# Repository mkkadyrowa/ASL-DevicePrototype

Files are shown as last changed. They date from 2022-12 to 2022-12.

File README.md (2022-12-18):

# ASL-DevicePrototype
Includes designs, circuit diagrams, signal processing code, final report, laboratory notebook

We developed design skills to produce wearable american sign language device where the main concept was to have ring and fingernail devices emit and record IR waveform emissions with specific calculated frequency. We applied electrical engineering knowledge to create IR LED data acquistion module, band pass filter, and IR wave generatitng module using chips, circuitry electronics, measurement and power tools (e.g. oscilloscope, multimeter, power supply). We presented obtained data from oscilloscope where it showed how data was produced with specific frequency, data was collected using data acquisition module, and data was filtered using bandpass filtering. We had specific functitonal specifications such as voltage limit, IR LED wavelength, and frequency generated by the IR LED emitting circuit. We researched and practiced safety and sustainability standards. We remained under the project budget, utilized Gannt and PERT charts for project management. I worked with NI Multisim to create and test circuit diagrams of IR wave generating circuit, data acquisition module, and filtering module online before creating them in the lab. We created PCB circuit diagrams for the above mentioned IR wave generating circuit, IR data detection and acquisition module. We simulated, tested, troubleshot, and tried alternative approaches for the three modules were creating using Falstad, NI Multisim, and TI online simulation tool. We soldered the circuit diagrams as SMD models and perforated board model after testing them on breadboards. The testing of the systems included having IR wave generating circuit emit IR waves in specific frequency using 5 V power input. Next, IR data acquisition module recorded IR waves with specific frequency and graphed data on oscilloscope where captured frequency and voltage was observed. Active bandpass filtering module received acquired IR data, filtered outt optical noise, and returned a filtered signal where frequency and voltage was analyzeed. I learned team and project management, testing and troubleshooting electrical prototypes, regulations and standards, presenting data and biweekly updates, finding alternative solutions, designing parts on SolidWorks, soldering, PCB soldering using SMD models, using NI Multisim for designing and testing circuit diagrams, etc.

Summary: Designed and built a wearable American Sign Language device prototype that leveraged infrared (IR) waveforms from ring and fingernail sensors with specific frequency. Used NI Multisim, SolidWorks, SMD Models.

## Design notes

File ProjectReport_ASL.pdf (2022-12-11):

Senior Design Project II (BE-4355-001)

A Lightweight Wearable American Sign Language Translation Device

Faculty Mentor: Dr.Oguz Yetkin

Team Members: Ruqaya Abdulzahraa, Savannah Chiweshe, Mahri Kadyrova, Ridhaa Shariff

Team: Vixen

Bioengineering Department at The University of Texas at Arlington

Submission Date: 26

th April 2022

2. Executive summary

The main goal of this project is to create a lightweight, wearable American Sign Language (ASL)

translation device. Currently, over 5% of the world’s population lives with a hearing disability. It is

estimated that by the year 2050, 1 in every 10 people will have a hearing disability (1). The overall aim

of this project is to create a fully functional translation device that will diminish the current

communication barrier that exists. Through our research, we found that there are many devices that are

currently being developed with similar goals. Many of these devices are glove-based, making them

cumbersome to use, as they limit the user’s ability to perform everyday life tasks. We attempt to

overcome this issue by designing the device to be glove-less with no necessity for it to be connected to

any external computers, monitors, or network. It is composed of five wireless fingernails, five wired

rings that are connected via thin wires to a wrist-worn central processing unit. The wrist-worn unit is

composed of an Arduino Mega, Raspberry Pi, and a 9V battery. These components are encased in a box-

like enclosure with a Liquid Crystal Display (LCD) screen and a speaker mounted on the side. The

device will achieve hand gesture recognition using 850 nm infrared (IR) light-emitting diode (LED)

emitters in the fingernails and rings. The IR LEDs (Light Emitting Diode) in the rings will trigger the IR

LEDs in the fingernails and thus turn them on. Each ring will have IR receivers that will be able to

measure the intensity of the signals produced by the IR emitters in the fingernails. They will then send

this information to the wrist-bound Raspberry Pi to translate it through a trained neural network, which

is coded using Python, and produce the corresponding letter to be displayed on the LCD screen and

through the speaker. Our produced device will be the 9th generation production. Previous generations of

the device relied on digital filtering, which has been proven to hinder the performance of the device as it

results in inaccurate translating different gestures. Our novelty is implementing a new analogue filtering

system, which aims to fix this issue. We envision having square waveform generators in the fingernail

devices and filters in the ring devices. The specifications that we set for this project are that the device

should be lightweight (less than 400 g) and not rely on an external computer. The functional

specifications are that the device can recognize and translate the ASL alphabet, be at least 95% accurate,

be able to differentiate different frequencies, not pose any optical hazard, and have a life span of 4

hours. One of the main specifications is that the device must be below 400 grams, after calculating the

final device weight, we measured it to be 375.88 grams, which meets the weight limit. Another criterion

is that it must not rely on any external device, which our device meets that standard. The device must,

however, be connected to a power source, such as a power bank.

3. Table of contents

5.3 Engineering, safety, environmental, and sustainability standards that are applicable and are to be observed

6.2.1 Drawings, schematics and other illustrative means of showing the system and the subsystems for the

6.5 Assessment of chances of success based on the selected design concept and engineering computations and

8.1 Detailed description of the testing procedures/protocols for determining the physical and functional

4. Introduction

4.1 Significance and benefits of the project

American Sign Language is the third most used language in the United States. Across the country, 10

million are hard of hearing and close to 1 million are functionally deaf (2). Furthermore, 2-3 of every

1000 children are born with a detectable level of hearing loss, and 90% of this population is born to

hearing parents, thus creating a communication divide within families (3). In a work environment,

accommodations for ASL users are minimal to none. Moreover, the deaf awareness training in

workplaces has low results. And in the past few years, due to Pandemic it has become more difficult for

ASL users to sign and understand their coworkers as interpreters are not always “pinned” during video

calls (4)(5).

4.2 Existing similar systems

Currently, there are no ASL translation devices on the market, but there are several institutions and

groups that have researched and designed similar devices. These institutions include Cornell University

where Electrical and Computer Engineering students designed a wearable glove that uses Machine

Learning algorithms to translate signed language into spoken English (6). This prototype uses Spectra

Symbol Flex-Sensors to measure how much a finger is bent and a three- axis accelerator and gyroscope

to identify the orientation and movement of the hand. The data from the sensors is then analyzed using

ATmega1284p microcontrollers and sent to a main PC (Personal Computer) unit and run-in conjunction

with a python script and then translated. As a result, their final device had an accuracy of 98%,

translating 28 ASL signs, however, these values are dependent on the user's hand size which creates

challenges differentiating between certain letters.

Similarly, Michigan State University developed a deep learning-based sign language translation

technology implementing Leap Motion for light-based sensing of skeletal joints. In addition to this, the

technology uses a recurrent neural network model the spatial structure and temporal dynamics of the

extracted ASL characteristics, and a probabilistic framework based on Connectionist Temporal

Classification, allowing for both word and sentence level ASL translation of 94.5% accuracy (7).

However, this design is different from other translation devices as it does not incorporate any type of

glove which other devices lean towards.

4.3 Objectives of the project

The main objective of this device is to narrow the communication gap between ASL and non ASL users

by allowing the language to be used and understood between the two parties without the need of an

interpreter. This communication barrier makes it hard for ASL users to express themselves and

communicate and the reliance on an interpreter would hinder them and may also lead to

miscommunication due to human error upon translating. It is also not feasible to carry around a device

using a camera and angle it correctly to always interpret hand movements. Thus, this device is non-

intrusive, portable, and easy to use across all ages as it does not rely on external computers.

4.4 Distinguishing features of the proposed system compared to existing similar systems

Compared to other devices currently underway, our device aims to occupy less space to leave the user’s

hand as free as possible leaving the fingertips exposed to allow easy access to touch screen devices, unlike

the glove-based devices. This device will implement modulated infrared frequencies for detection of

signed hand positions. This information from the IR emitters is then transferred to a system with a trained

neural network to identify the corresponding signed letter. Additionally, to achieve the objective of

convenience and portability, the device will have wireless fingernails, and rings connected to the wrist

component by minimal wires. The device will also rely on an analog system to communicate between the

rings and fingernails components as well as filter different IR emitted frequencies.

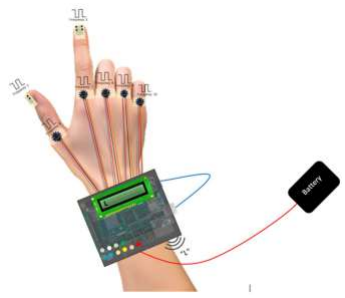
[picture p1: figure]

Figure 1. Device components: central processing wrist unit, wired rings, wireless fingernails

4.5 A brief outline of how this written report is organized

The remainder of this report includes detailed information about the project specifications, which

includes detailed quantitative functional and physical specifications, the safety and sustainability, as well

as any constraints of the device that may be identified. The report will also include detailed design

information including the rationale behind it. We will also discuss test results and present simulation

results as well as any schematics and computations that were done. We also discuss any fabrication that

was done, including building the circuits. Finally, we discuss the project costs and present detailed tables

of costs and vendors as well as any laboratories and facilities used.

5.Project Specifications

The device must meet several necessary specifications and safety requirements to operate properly and

avoid any safety hazards within the provided constraints.

5.1 Detailed quantitative functional specifications

The main components in the subsystem included breadboards. The three subsystems were waveform

generating circuit, detection circuit, and active bandpass filter circuit.

Waveform generating circuit consisted of the following circuit components: 555 Timer, resistors,

capacitors, and IR LED. The IR LED was secreting 850 nm light and the IR LED that was used in this

circuit was an SMD model. To power the subsystem, voltage supply was used. The voltage values used were 5 V or 3 V. Overall subsystem was designed to function at 5 V because the main CPU unit

contains Arduino Mega, and it provides the voltage supply of 3 V or 5 V.

Waveform generating circuit included 555 Timer. The primary function of 555 Timer was to produce

square waveforms that oscillate at a specific frequency. To obtain the desired frequency, resistor and

capacitor values were changed on the circuit which can be found in Figure 4.

In the above-mentioned circuit, values of resistors RA and RB, and the capacitor value of C2 were the

main components in determining the desired frequency. The desired frequencies for this project included

18 kHz, 38 kHz, 56 kHz, 77 kHz, 98 kHz, 114 kHz, and 132 kHz. In the future, a total of 10 or 15

unique frequencies must be generated to account for two to three transponders in each ring. To calculate

the unique frequencies’ resistors and capacitor values, the following formula was utilized:

f =

1.44
(RA+RB)∗C2

[1]

The above formula provided rough values of resistors and capacitor and it did not provide exact values.

The next step to obtain the resistors and capacitor values, NI Multisim was utilized to obtain a more

approximate value of the resistors and capacitor.

The voltage input for the waveform generating circuit included 3 V and 5 V. The output of the

waveform generating circuit was attenuated and the values can be observed below:

Table 1. The voltage values of the waveform generating circuit.

Vin | Vout
3 V | 1.96 V
5 V | 2.60 V

The detection subsystem consisted of phototransistor and resistor components. The phototransistor was

specified to detect 850 nm and the model that was used for detection subsystem was SMD model. The

resistor value that was finalized to be used was 1 MΩ.

To power the subsystem, voltage supply of values 3 V and 5 V were used. The phototransistor needed to

be pointed at the IR LED at 90 degrees to be able to detect the emitted signal. The detected signals were

very attenuated and the following voltage values were observed for phototransistor detection subsystem:

Table 2. The voltage values of the detection subsystem.

Vin | Vout
3 V | 200 mV
5 V | 500 mV

The third subsystem, the active bandpass filter, consisted of the following circuit components: dual

Operational Amplifier (op-amp), resistors of different values and capacitors. To power the subsystem,

voltage supply was used. The voltage supplied was also 5 V or 3 V as the overall system was designed

to function at 5 V as mentioned above.

The main purpose of the dual op-amp in this circuit was to provide isolation between the two sub-filters

and amplify the voltage going through the two stages of the bandpass filter (the high-pass filter and the

low-pass filter). Furthermore, to obtain filters with the desired bandwidth an online Texas Instruments

program was used to get filters that worked with the op-amp available to us. The bandpass filter in

Figure 8 was obtained for the 14-22kHz filter but a lot of testing and changing of resistor values was

needed to obtain a functioning filter.

To test the functionality of the filter, a waveform generator was used to test the change in voltage at a

range of frequencies. Amplification of voltage was expected at frequencies in the bandwidth and

attenuation of voltage was expected at frequencies outside the bandwidth. The following results were

obtained:

5.2 Detailed quantitative physical specifications

5.2.1 Lightweight

The overall device needs to be lightweight to avoid discomfort when used for extended periods of time.

The device should not weigh over 400 grams to allow it to be easy to carry around.

5.2.2 External devices

The device should not rely on any external devices to function. All audio, visual, and data outputs must

be independent without the reliance on an external laptop, phone, motor, keyboard, mouse, or network

connection. The power system of the device should also not be excessively bulky or large. The device

should also be portable.

5.3 Engineering, safety, environmental, and sustainability standards that are applicable and are to be

observed

5.3.1 Engineering and safety standards

Over-exposure to IR LED light can cause optical damage to the human eyes. Hence, in the designing of

this device, we made sure to adhere to the guidelines set forth by the International Electrochemical

Commission’s IEC62471 which state that the duration of exposure of the infrared light should be under

10 seconds and the wavelength should be within the 180 nm to 3000 nm range at 1 meter (8). With this

in mind, we will implement a TPL 5111 timer in all circuits that will limit the duration of IR LED light

exposure to 50ms, and the wavelength emitted will be 850 nm. Circuit building and soldering will play a

heavy role in the creation of our device. When working with circuitry, such as exposed wires and

running voltage, we complied with standards set forth by the National Institute for Occupational Safety

and Health (NIOSH). These standards state that the level of danger of a wearable electronic device is

reliant on these factors: voltage/current output of the device that comes into contact with skin, wetness

and/or any rupture on the skin, duration of electrical exposure, and the pre-existing health conditions,

age, and gender of the user (9). The process of soldering can release toxic fumes and dust that are

hazardous and if inhaled can cause occupational asthma or worsen existing asthmatic conditions, as well

as cause eye and upper respiratory tract irritation (10). To adhere to both guidelines wore protective

clothing and safety goggles and used a soldering fume extractor.

5.3.2 Environmental and sustainability standards

As mentioned before, the fabrication of this device required soldering using lead. This process releases

toxic fumes which require proper ventilation and disposal (11). A soldering fume extractor was used

during the soldering process and excess solder and any rags used were disposed of in the designated

hazardous waste disposals provided in the electrical engineering labs. Components such as batteries,

SMD models, and all other electronic components were recycled accordingly in the following facilities:

- Best buy electronic recycling: 1730 Pleasant Pl, Arlington, TX, 76015 (for computers, batteries,

and electronics)

- Master fibers, Inc: 2410 W. Division St, Arlington, TX, 76012 (for aluminum, copper,

electronics, and plastics)

- Public convenience center in Arlington (for circuit boards, electronic household items)

5.4 Cost constraints

The allocated budget given to us by the Bioengineering Department at The University of Texas at

Arlington was $500.00. Due to this project being a generational project, we were able to find many

components that we needed, such as breakout boards and jumper cable wires in our lab. Because of this,

we were able to reuse many of those components for testing purposes. We needed to buy a few specific

components, which will be listed below. Our team also requested access to the Electrical Engineering

Lab, which allowed us to use much of their equipment, such as the oscilloscopes, without an extra

charge. Overall, we spent $98.63 from our allocated budget. Our mentor, Dr. Yetkin, spent $45.82, that

is not included in the amount referenced above as it was spent by Dr. Yetkin and not from the budget we

received from the department. The total leftover amount is $401.37.

Table 3. Cost constraints.

Ceramic Capacitor Assortment Kit | $16.99
Resistor Assortment Kit | $12.99
NE555P Timers (12 units) | $9.35
Operational Amplifier Dual Op-amps (50 units) | $6.49
Soldering Kit | $7.48
Soldering Board | $7.98
Soldering Putty | $2.13
Potentiometers | $8.49
Multiplexer Breakout Board | $5.29
Multiplexers (10 units) | $21.42

5.5 Project duration constraints
The project took off in August of 2021, and our team had a goal of completing the project on April 7th ,

2022. This would give the team enough time to prepare for innovation day, which took place on April 11th, 2022, as well as finish any presentations required for the class and completing the final report.

However, after some extensive testing and research that took place in January of 2022, our team realized

that the original plan we had produced in the previous semester was not going to yield the desired

results. After performing more research, and with our mentor’s advice in mind, the team resorted to

proceeding in a different direction. Testing for our new plan was very extensive and took up most of the

semester. The reason for this being is our mentor had urged us to not proceed with any fabrication until

he approved the testing results, to ensure that the new filtering subsystem would benefit the device.

Requesting access to the Electrical Engineering Lab took a few days, which delayed the start of testing.

Another factor that contributed to delayed testing was the process of ordering and receiving parts, which

took approximately two weeks. A snowstorm that hit during the semester also hindered our testing

progress as campus was closed for a few days. Testing of the circuits continued through our original proposed deadline and concluded on April 21st, 2022.

5.6 Final project schedule

The following Gantt and PERT charts represent the timeline we followed throughout the semester, the

tasks carried out, and who was responsible for which task. The charts had to be altered after we realized

how much preliminary testing we had to conduct. Previous versions of the chart can be found in the

appendix.

Figure 2. Gannt chart of Spring 2022 semester activities.

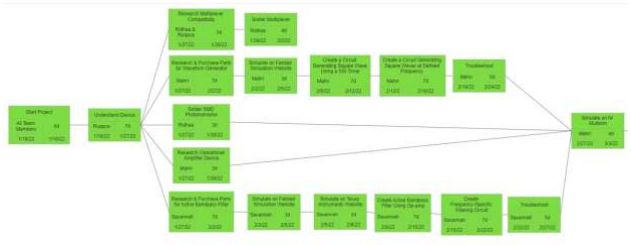
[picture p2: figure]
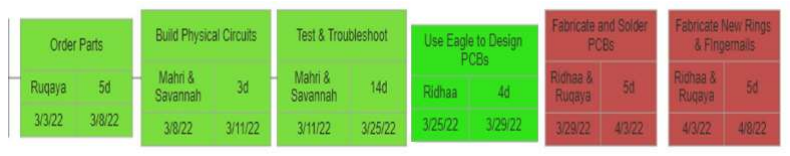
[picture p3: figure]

Figure 3. PERT chart of Spring 2022 semester tasks

6. Design

6.1 Description of the selected design concept and rationale behind it

The previous generations left a digital system that consisted of fingernails system, ring system, and CPU

unit. Most of the system utilized digital components and various codes that performed desired functions

like filtering and data acquisition. The shortcomings of the previous generations outweighed the benefits

and a new pathway needed to be explored. The current group focused on analog components of the

system and started from zero.

The chosen pathway included building fingernail and ring subsystem with chips, resistors, and

capacitors. The current group performed testing and troubleshooting throughout the whole time. The

main design of the project that was chosen included working with breadboards, perforated boards,

measurement tools, and simulation tools.

The circuits that the group started out with included waveform generating circuit, detection subsystem,

and active bandpass filters. To test the obtained circuits, simulation was performed using NI Multisim

and Falstad online tools. To test the subsystems in real life, the circuits were constructed on breadboards

using 555 Timer, operational amplifier, resistors, capacitors, phototransistor, and IR LED.

Simulation tools were advised by the course professor Dr. Behbehani and project mentor Dr. Yetkin,

who suggested simulating the subsystems first in the online simulation tools and then build them. The

rationale was to analyze if the potential subsystem does work in an online environment and then build it

in real life to test it.

The testing in real life was done on breadboards because of flexibility and ease of building the

subsystems and obtaining the measurements using measurement tools such as oscilloscope and

multimeter.

6.2 Description of major subsystems

The main subsystems of the chosen design consist of waveform generating circuit, detection subsystem,

and filter.

The waveform generating circuit utilizes 555 Timer that outputs square waves that have a unique

frequency. This unique frequency is obtained by a unique combination of resistors and capacitors. The

circuit powers 850 nm IR LED to flash at unique frequency that was mentioned. The IR LED used was

in an SMD form.

The detection subsystem consists of the phototransistor detection component that is in SMD model, and

it is designed to detect 850 nm IR light. The detection subsystem circuit also utilizes a high value

resistor.

Lastly, the active bandpass filter having a bandwidth from 14 kHz-22 kHz was set up on a breadboard

using a dual op-amp, a range of resistors and 1nF capacitors. This filter consisted of a high-pass filter in

cascade with a low-pass filter, separated by the op-amp. The subsystem was supplied with a voltage of

around 5 V for optimal function. This subsystem's purpose was to amplify the voltage of signals at

frequencies in the bandwidth range and attenuate the voltage of signals at frequencies out of the

bandwidth.

6.2.1 Drawings, schematics and other illustrative means of showing the system and the subsystems for

the device

The group focused and created three subsystems overall. Those subsystems are waveform generating

circuit, detection subsystem, and active bandpass filter. The diagram of circuits and PCBs of those

subsystems will be shown below:

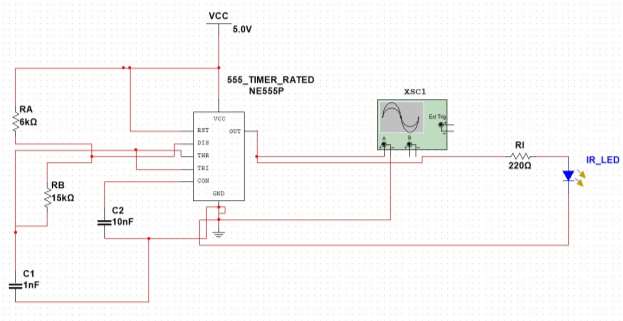
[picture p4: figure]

Figure 4. Circuit diagram of waveform generating circuit.

It is worth noting that the resistor values of RA and RB as well as capacitor value of C2 change depending

on the desired frequency needed. The voltage supply can also change and is usually either 3 V or 5 V

but the final system will utilize 5 V. The above subsystem was built on breadboard and miniaturized into

a perforated board as well, which will be discussed later in the report.

Figure 5. Circuit diagram of detection subsystem.

It is worth noting that the voltage supply could either be 3 V or 5 V but the final system will utilize 5 V.

The above subsystem was built on breadboard and miniaturized into a perforated board as well, which

will be discussed later in the report.

The following diagrams are the PCB Eagle diagrams of the waveform generating circuit and detection

subsystem:

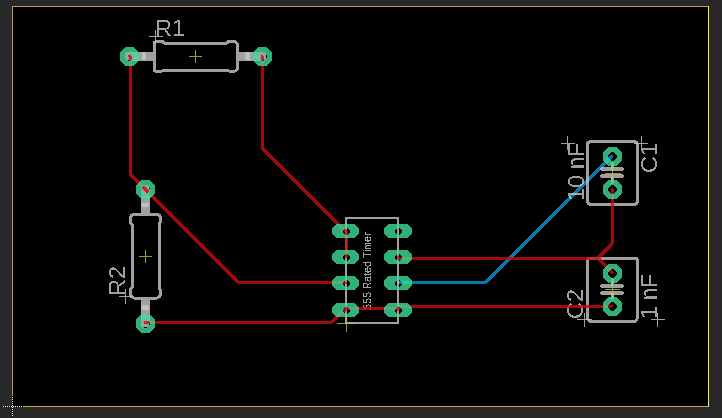
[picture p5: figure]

Figure 6. PCB circuit of waveform generating circuit.

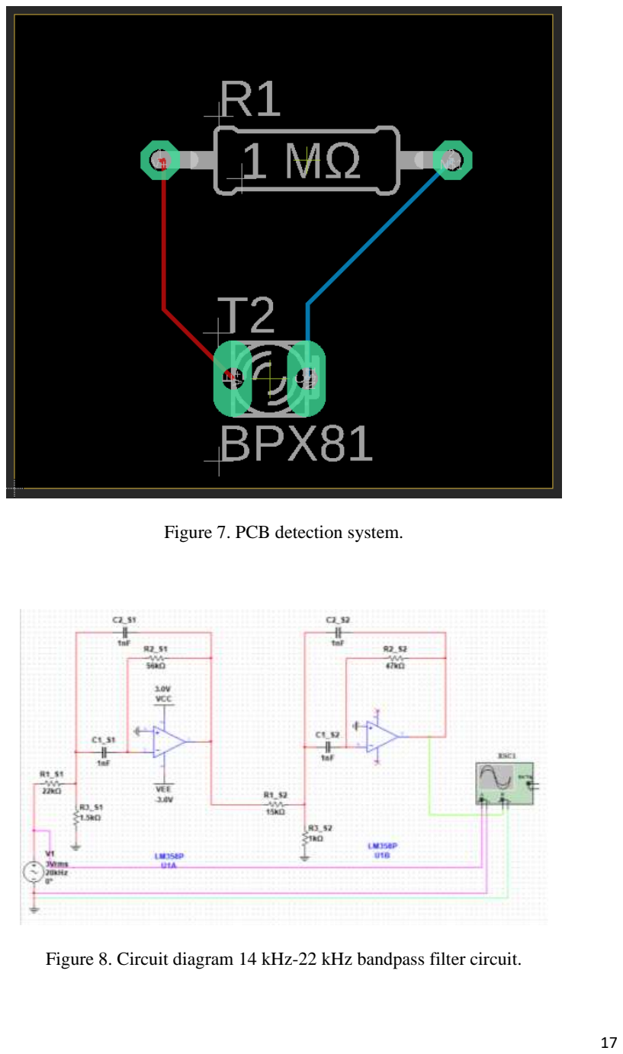
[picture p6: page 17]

Figure 7. PCB detection system.

Figure 8. Circuit diagram 14 kHz-22 kHz bandpass filter circuit.

As mentioned previously, the voltage supply could either be 3 V or 5V, but the final system will utilize

5 V. The above subsystem was built on breadboard and miniaturized into a perforated board as well,

which will be discussed later in the report.

6.3 Engineering design computations

The three subsystems that were worked on by the group include waveform generating subsystem

detection subsystem, and an active bandpass filter.

The main computations carried out for the waveform generating subsystem included figuring out the

resistor and capacitor values to obtain desired frequencies. Another computation that needed to be

Figured out was the voltage supply that powered the circuit. As mentioned above the frequencies that

were decided on include 18 kHz, 38 kHz, 56 kHz, 77 kHz, 98 kHz, 114 kHz, and 132 kHz.

To calculate the unique frequencies’ resistors and capacitor values, the following formula was utilized:

f =

1.44
(RA+RB)∗C2

[2]

The above formula provided rough values of resistors and capacitor and it did not provide exact values.

The next step to obtain the resistors and capacitor values, NI Multisim was utilized to obtain a more

approximate value of the resistors and capacitor. The next subsystem is the detection subsystem. The

main computational analysis performed focused on input voltage, output voltage and resistor value. The

final detection subsystem circuit was represented in Figure 5.

The voltage input applied was either 3 V or 5 V and it was settled that for the final design 5 V will be

used for both waveform generating and detection subsystems because the main CPU unit of the device

utilizes 5V.

Table 4. The voltage values of the waveform generating circuit.

Vin | Vout
3 V | 1.96 V
5 V | 2.60 V

The output voltage of the detection subsystem was very attenuated, and our mentor suggested increasing

the resistor values. The subsystem was tested using various resistor R1 values and the following values

were recorded:

Table 5. The output voltage values of the detection subsystem using different R1 values.

R1 (kΩ) | Vout
680 | 15.2 mV
1000 | 150.0 mV

Following the change of the resistor R1 values the input voltage of 3V and 5V were applied to obtain the

output voltage value of the detection subsystem and the values can be observed in the table below:

Table 6. The voltage values of the detection subsystem.

Vin | Vout
3 V | 200 mV
5 V | 500 mV

As mentioned earlier, to obtain filters with the desired bandwidth an online Texas Instruments program

was used to get schematics of filters that worked with the dual op-amp available to us. Once the circuits

were built, some testing was done to see how well the bandpass filters attenuated voltage of frequencies

out of the passband and amplified frequencies in the passband. The results showed that the circuit was

not accurate, and some adjustments were made using the following equations and calculations were

needed, allowing us to achieve the circuit in Figure 8

C = C1 = C2 | [3]
k = 2 ⋅ fcenter ⋅ C | [4]

R1 =

Q 1⋅k | [5]

R2 =

Q (2⋅Q²−1)⋅k | [6]

R3 =

2Q k | [7]
fcenter = 18 kHz | [8]

Q =

fcenter
BW
= 2.25 | [9]

6.4 Simulation results

The three subsystems that were built and tested for the project included a lot of simulations, failures, and

troubleshooting.

The main tools that were used to simulate the waveform generating circuit were Falstad online tool and

NI Multisim desktop tool. The following initial circuit of waveform generating subsystem was simulated

using Falstad:

Figure 9. Circuit diagram of initial waveform generating subsystem.

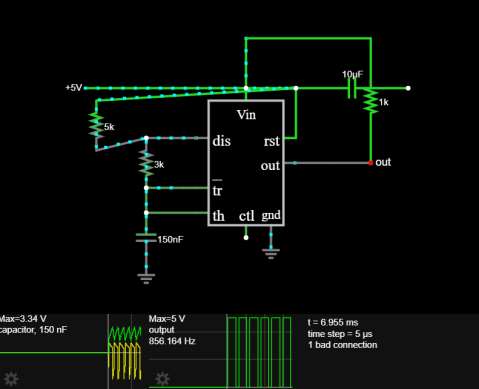
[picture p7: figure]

Figure 10. Falstad simulation of the initial waveform generating circuit.

As can be observed from the above simulation, there is a bad connection that does not provide accurate

values for the frequency. Troubleshooting was attempted and the results were unsuccessful. Thus, it was

suggested by our mentor to try NI Multisim desktop simulation tool. The above initial circuit of

waveform generating circuit did not provide any results in the NI Multisim, so a new circuit was

researched and simulated. The new waveform generating circuit is represented below:

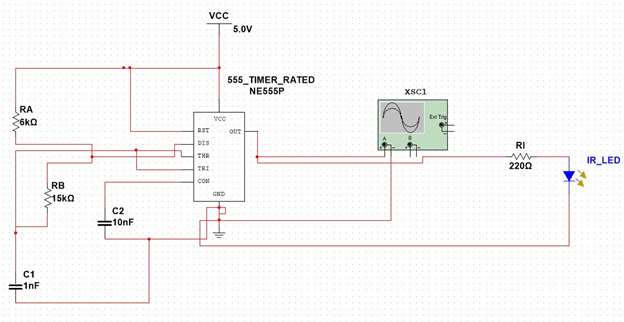
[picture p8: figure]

Figure 11. The final waveform generating circuit’s diagram.

The above circuit was tested after changing the RA, RB, C1 and C2 values. When simulated, NI Multisim

provided a graph from which the frequency was calculated by utilizing the time stamps for each cycle.

An example of the graph from NI Multisim is represented in the following Figure:

Figure 12. An example of the NI Multisim resulting graph for the waveform generating circuit tested.

The simulated values and the obtained frequencies have been put into the following table:

Table 7. The simulated resistor and capacitor values and obtained frequency values.

Frequency

(kHz)

RA (kΩ) | RB (kΩ) | C1 (nF) | C2 (nF)
~8.0 | 5.1 | 33 | 1 | 10
~16.4 | 4.7 | 3 | 1 | 10
~25.5 | 4.7 | 22 | 1 | 10
~72.5 | 4.7 | 4.7 | 1 | 10
~89.3 | 4.7 | 3 | 1 | 10
~104.0 | 3 | 3 | 1 | 10
~101.0 | 4.7 | 2.2 | 1 | 10
~121.0 | 3 | 2.2 | 1 | 10

The next step was to test the above obtained resistor values to acquire exact values of the resistors and

capacitor to produce square waveforms at desired frequency. The following frequencies were tested, and

the resistors and capacitor values were finalized:

Table 8. The final resistors and capacitor values produce the desired frequency of square waveform

oscillation.

Frequency

(kHz)

RA (kΩ) | RB (kΩ) | C1 (nF) | C2 (nF)
~18 | 5.1 | 33 | 1 | 10
~38 | 2.2 | 15 | 1 | 10

The voltage input for the waveform generating circuit included 3 V and 5 V. The output of the

waveform generating circuit was attenuated and the values can be observed on Table 4.

The Vout values were fluctuating but the values were never high enough for our testing which will be

explained when discussing detection subsystem.

Detection subsystem could not be simulated in online tools because online tools lacked IR components.

The project utilizes components such as 850 nm IR LEDs and 850 nm SMD phototransistors and the

online tools did not have the needed components. When simulating the detection subsystem with

different phototransistor components, the result contained no signal, and it was confirmed by our mentor

that such models may not work in online environments.

The detection subsystem consisted of SMD model of 850 nm phototransistor and 1 MΩ resistor

components. Due to the low output voltage values that were recorded throughout many testing

procedures, resistor value of 1 MΩ was utilized for the circuit and following results obtained can be

observed on Table 6.

It is possible to observe that the output voltage values are still very attenuated. These values were the

highest voltage output values obtained with the resistor value of 1 MΩ. The resistor values less than

1MΩ gave much smaller voltage output values than above.

The attempted simulation of amplifier circuit was challenging in a way that simulation of the amplifier

circuit gave promising results but when tested on lab bench using power supply and oscilloscopes the

subsystem either failed or got fried.

The following inverting op-amp was built on breadboard and tested:

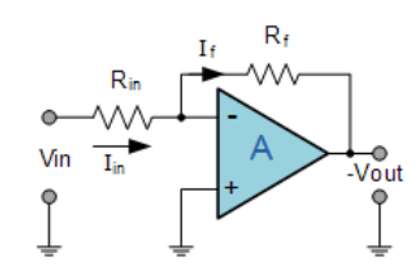
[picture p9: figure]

Figure 13. Inverting operational amplifier circuit #1.

Tha above circuit was connected to the detection subsystem circuit and the main purpose was to amplify

the signal detected by the phototransistor. More specifically, the purpose was to amplify the voltage

signal of the obtained signal. The above circuit has the gain that can be calculated using the following

formula:

Gain =

Vout

Vin

= −

Rf

Rin

[10]

Here the Rf and Rin were set to be 10 kΩ and 1 kΩ. The calculated gain was –10³ where the negative

means that the output signal will be inverted.

Table 9. The output voltages of detection subsystem with and without amplifier circuit connected.

Vout of detection subsystem without amplifier | Vout of detection subsystem with amplifier
150 mV | 560 mV

The output voltage of the detection subsystem without amplifier served as the input voltage for the

amplifier circuit and the gain was calculated to be:

Gain =

560 mV
150 mV
= 3.733 | [11]

As can be observed from the gain value as well as the output voltage of amplifier circuit that is

connected to the detection system, the final values are not amplified properly so new attempts at

amplifier circuit were performed.

A new amplifier circuit was simulated first before building it right away like was done with the previous

amplifier mentioned above. The following diagram was created using NI Multisim:

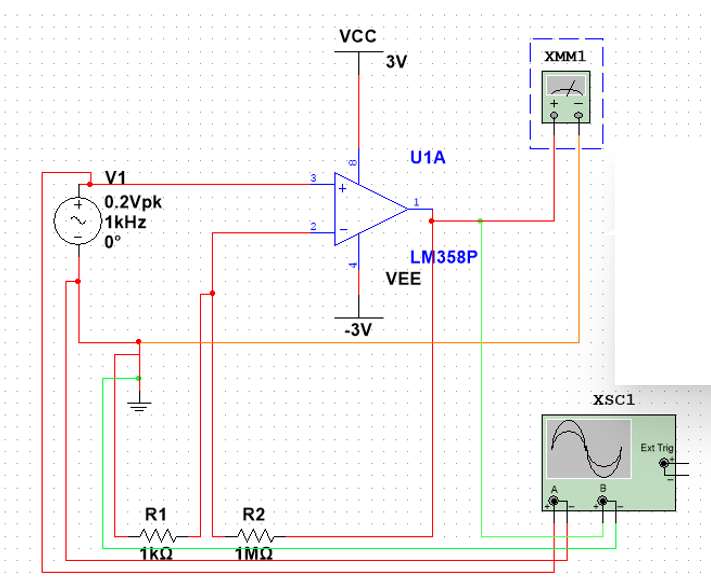
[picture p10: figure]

Figure 14. Amplifier circuit #2.

The above circuit contains operational amplifier, resistors, and AC voltage supply. The AC voltage

supply was chosen to mimic the signal output of detection subsystem which will act as the AC voltage

supply to the amplifier circuit. As can be seen from the circuit, an input voltage of 0.2 V was provided,

and the output voltage was 2.187 V. The gain of this computation was:

Gain =

2.187 V
0.2 V
= 10.935 | [11]

The next step included building the amplifier circuit #2 on a breadboard. The obtained results included

no signal when connected the amplifier circuit to the detection subsystem. Researching and building a

new amplifier circuit was attempted. The new simulated circuits did not work, provided small gain, or

burned. The lack of time and guidance resulted in discontinuation of amplifier circuit research.

To test the 14-22kHz bandpass filter in Figure 8, the filter was supplied with a voltage of 3-5V using a

power supply and connected to a function generator. The input and output of the filter were then

connected to an oscilloscope to visualize how the signals changed when different frequencies were fed

into the bandpass filter.

The 14-22kHz bandpass filter was fed frequencies from 10-30kHz consecutively and the voltage of the

bandpass filter was recorded at each frequency, seen in Table 10 and Figure 16 below.

Table 10. The change in output voltage of the 14-22kHz bandpass filter at a range of frequencies.

Frequency
of
Waveform
Generator
(kHz)

Amplitud
e of
Function
Generator
(Vpp)

Input
Voltage
of Op
Amp
(V)

Frequency
from filter
input
(kHz)

Frequency
from filter
output
(kHz)

Vpp of
filter
input (V)

Vpp of
filter
output (V)

Amplitude of
filter input (V)

Amplitude of
filter output
(V)
10 | 3 | 3 | ~10 | ~10 | 3.4 | 0.320 | 3.2 | 0.320
11 | 3 | 3 | ~ 11 | ~ 11 | 4.0 | 0.264 | 3.2 | 0.264
12 | 3 | 3 | ~12 | ~12 | 3.6 | 0.280 | 3.2 | 0.152
13 | 3 | 3 | ~13 | ~13 | 4.0 | 0.288 | 3.0 | 0.176
14 | 3 | 3 | ~14 | ~14 | 3.4 | 0.366 | 3.2 | 0.248
15 | 3 | 3 | ~15 | ~15 | 3.4 | 1.64 | 3.2 | 0.840
16 | 3 | 3 | ~16 | ~16 | 4.0 | 1.68 | 3.2 | 1.68
17 | 3 | 3 | ~17 | ~17 | 4.2 | 1.72 | 3.0 | 1.72
18 | 3 | 3 | ~18 | ~18 | 4.2 | 1.76 | 3.2 | 1.76
19 | 3 | 3 | ~19 | ~19 | 4.0 | 1.72 | 3.2 | 1.64
20 | 3 | 3 | ~20 | ~20 | 3.6 | 1.68 | 3.2 | 1.56
21 | 3 | 3 | ~21 | ~21 | 3.6 | 1.56 | 3.2 | 1.44
22 | 3 | 3 | ~22 | ~22 | 4.8 | 1.6 | 3.2 | 1.6
23 | 3 | 3 | ~23 | ~23 | 3.4 | 1.52 | 3.0 | 1.52
24 | 3 | 3 | ~24 | ~24 | 3.4 | 1.48 | 3.2 | 1.48
25 | 3 | 3 | ~25 | ~25 | 3.4 | 0.920 | 3.2 | 0.920
26 | 3 | 3 | ~26 | ~26 | 4.4 | 0.800 | 3.2 | 0.800
27 | 3 | 3 | ~27 | ~27 | 3.8 | 0.680 | 3.2 | 0.600
28 | 3 | 3 | ~28 | ~28 | 3.8 | 0.560 | 3.2 | 0.560
29 | 3 | 3 | ~29 | ~29 | 4.4 | 0.520 | 3.2 | 0.520
30 | 3 | 3 | ~30 | ~30 | 3.8 | 0.480 | 3.2 | 0.480

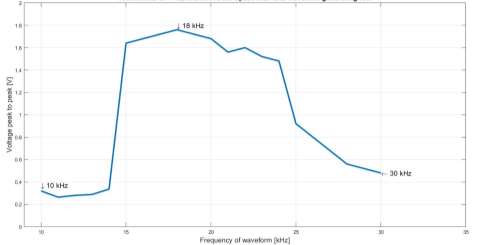
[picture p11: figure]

Figure 16. Change in output voltage of 14-22kHz Active Bandpass Filter.

As seen in Table 10 and Figure 16 above, with a 3V voltage supply the voltage output of the filter was

attenuated from 10kHz to about 15kHz range, and slightly amplified between 16kHz-24kHz, then

attenuated again from about 25kHz-30kHz. Although the voltage was amplified within the bandwidth,

we observed uneven distribution of the voltage compared to what was expected. Higher voltage

amplification was expected as 3V was supplied, however, the maximum output voltage was

approximately 1.76V. Additionally, the bandwidth range calculated was not as accurate as was expected.

To further analyze the results of the 14-22kHz bandpass filter and identify how accurately it was

working, the frequency response of the filter was calculated using the voltage transfer function [12]

below where Vout ￼￼ is the output signal voltage, Vin is the input signal voltage, j is √ − 1 and

￼ω is the radian frequency.

H(jω) = [

Vout(jω)
Vin(jω)
] | [12]

The frequency response graphed in Figure 17 below shows how the gain of the output responds to input

signals at different frequencies. The highest gain was at the center frequency (18kHz) as expected,

however, the gain still fluctuated and had uneven distribution specifically within the passband.

Furthermore, the gain did attenuate as frequencies moved out of the passband.

Figure 17. Frequency Response of 14-22kHz Active Bandpass Filter.

6.5 Assessment of chances of success based on the selected design concept and engineering

computations and simulations

Due to the team needing the basis of the project midway through the year, additional research needed to

be done in the second semester, which lead to us having a delayed start to testing. Our mentor also

strictly urged us to not fabricate anything until he approved all testing done. This expanded our testing

and troubleshooting phase, thus preventing us from fabricating anything. However, considering all

limitations the team faced, our simulations provide a great foundation for future generations to build

upon. They show great promise for the future direction of the project in switching to an analog filtering

subsystem, rather than the current digital filtering subsystem.

7. Fabrication

7.1 Details of how the device prototype was fabricated

The three subsystems that were fabricated included waveform generating subsystem, detection

subsystem, and a bandpass filter. Some of these subsystems needed preliminary fabrication of some

SMD models before being fully fabricated.

The initial fabricated model included building the subsystems on breadboard. To build the subsystems

on breadboard, a lot of research has been done to find the right circuits. The next step included obtaining

parts such as chips, resistors, capacitors, breadboards, wires, and SMD devices.

SMD devices included soldering SMD model IR LED and phototransistor to two wires on each

conducting side of the SMD model. The following tools were used to solder an SMD model to wires:

soldering iron set, tips, cleaning sponge, metal brass wool, tweezers, soldering wire, and SMD models.

The following steps were utilized to solder the SMD models to wires:

1. Use the tweezers to position the SMD model.
2. Set the correct tip on the soldering iron before turning it on.
3. Turn on the soldering iron and smoke absorber.
a. Set the heating temperature to 350 C.
4. Heat one side of the SMD model for 2-3 seconds.
5. Add some solder onto the heated part of the SMD model.
6. Have the jumper wire ready and heat up the jumper wire ending after placing it on one side of

the SMD model.

7. Make sure the wire is not moving and that it is connected correctly.
8. Utilize metal brass wool or cleaning sponge to get rid of the extra solder on the tip of the

soldering iron.

9. Repeat the same steps for the other side of the SMD model.
10. Turn off the tools from power supply, clean the bench, and clean hands after finishing the

procedure.

11. Test the SMD model to see if it is working.

The breadboard devices were tested and troubleshot for quite some time before the miniaturization was

performed. For the miniaturization, perforated boards were used to solder all the components on. The

miniaturized subsystems included an 18 kHz waveform generating circuit, detection subsystem, and 14-

22 kHz active bandpass filter. Once fabricated, the perforated boards were tested for connectivity using

a multimeter to ensure that there was no short circuiting or damage to the subsystems.

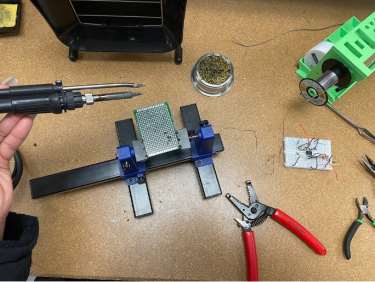
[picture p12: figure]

Figure 18. Set up for soldering of perforated boards

7.2 Figures, photos, and other forms of illustrations of the device

-The three subsystems that were fabricated included breadboard perforated board prototypes of

waveform generating circuit, detection subsystem, and active bandpass filter.

The following are the figures representing breadboard prototypes:

Figure 19. Waveform generating circuit as a breadboard model.

Figure 20. Detection subsystem as a breadboard model.

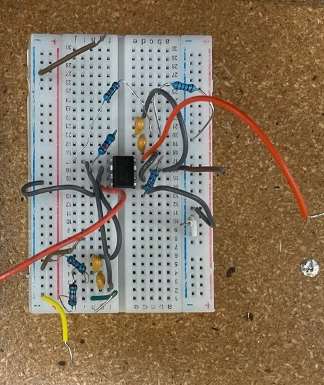
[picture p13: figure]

Figure 21. 14kHz-22kHz bandpass filter circuit as a breadboard model.

The following are the figures representing perforated board prototypes:

Figure 22. 18 kHz waveform generating circuit as a perforated board model.

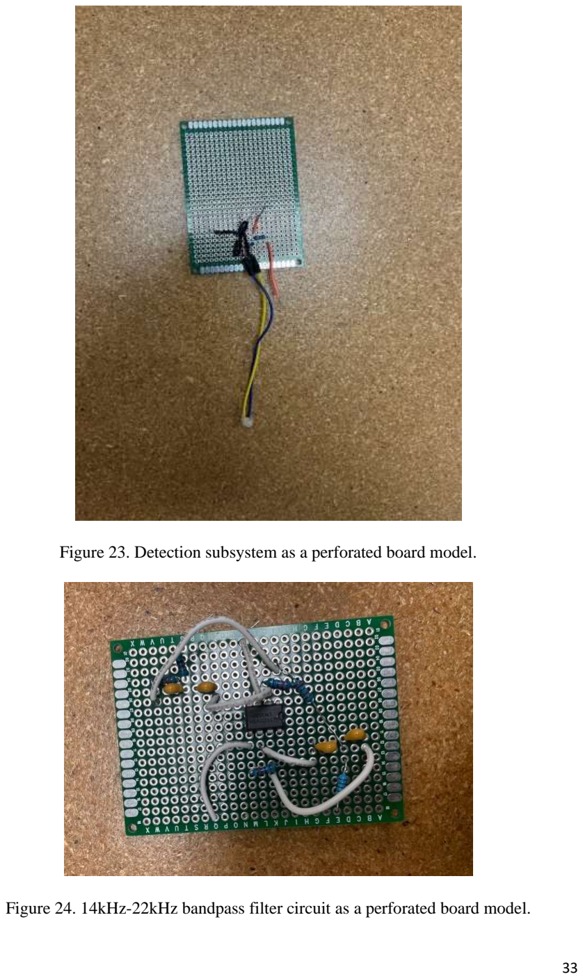
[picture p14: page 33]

Figure 23. Detection subsystem as a perforated board model.

Figure 24. 14kHz-22kHz bandpass filter circuit as a perforated board model.

7.3 Modifications to the design that were needed to achieve the design specifications

The three subsystems that were developed and attempted to improve are waveform generating circuit,

detection subsystem, and filter.

The initial waveform generator circuit had challenges that needed to be addressed. Those challenges

included the output of the circuit being unstable. This was measured by analyzing the frequency values

that were provided through oscilloscope measurements. The frequency values were unstable, and the

target frequency was hard to achieve. To address that issue, troubleshooting, research, and simulations

were performed. When troubleshooting with a mentor, the issues could not be fixed, and it was decided

to do more research about waveform generating circuits that produce a square waveform with a unique

frequency. Research has been done and new circuits were simulated. The optimal circuit was found and

tested. The new optimal circuit provided a signal that was stable and the frequency values on the

oscilloscope did not fluctuate as they used to in the initial circuit designs. Another challenge of the

waveform circuit included attenuated voltage output. Due to the limitation of being able to use only up

to 5 V, the output voltages were attenuated and hard to work with. Building and testing amplifier circuits

were attempted but no successful outcome was achieved.

The following initial circuit was built and tested:

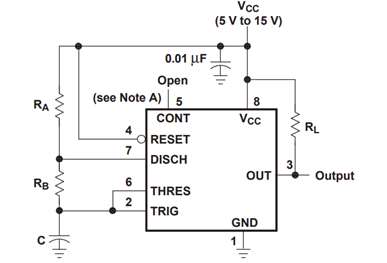
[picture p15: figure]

Figure 25. One of the initial testing circuits for the waveform generating system.

The above circuit was one of the initial circuits that was built and tested on to obtain target frequencies

of square waveforms on oscilloscope. It was used to test various values of resistors RA and RB and capacitor C to obtain the desired frequency. Below is the representation of the testing performed to

obtain a 38 kHz waveform generating circuit:

Table 11. The testing values of RA, RB, and C values to obtain desired frequency of 38 kHz on

oscilloscope.

RA (kΩ) | RB (kΩ) | C (nF) | Oscilloscope frequency (kHz) | Theoretical frequency (kHz)
5.1 | 3 | 0.01 | ~214.8 | 12973.0
5.1 | 3 | 1 | ~ 89.4 | 129.7
5.1 | 5.1 | 1 | ~70.2 | 94.1
5.1 | 33 | 1 | ~18.8 | 20.3
5.1 | 22 | 1 | ~26.3 | 29.3
5.1 | 15 | 1 | ~35.2 | 41.0
4.7 | 15 | 1 | ~35.6 | 41.5
3 | 15 | 1 | ~37.4 | 43.6
2.2 | 15 | 1 | ~38.2 | 44.7

Theoretical frequency was obtained utilizing the following formula:

| | f =

1.44
(RA+2⋅RB)⋅C

[13]

The following values were computed to obtain the desired frequency of 56 kHz waveform generating

subsystem:

Table 12. The testing values of RA, RB, and C values to obtain desired frequency of 56 kHz on

oscilloscope.

RA (kΩ) | RB (kΩ) | C (nF) | Oscilloscope frequency (kHz) | Theoretical frequency (kHz)
5.1 | 5.1 | 1 | ~ 70.8 | 94.1
5.1 | 5.6 | 1 | ~67.3 | 88.3
5.1 | 7.5 | 1 | ~57.2 | 71.6
5.6 | 7.5 | 1 | ~56.1 | 69.9

The obtained voltage values of the above subsystem when tested using oscilloscope are represented

below:

Table 13. The voltage values of the above initial 38 kHz waveform generating subsystem.

Vin | Vout
3 V | 720 mV
5 V | 1.96 V

The initial detection subsystem had challenges of phototransistor not being able to receive enough

voltage due to the resistor values that were used in the circuit. The attempt to fix that problem included

troubleshooting using various resistor values. It was found that more voltage was delivered when using 1

MΩ resistor value. Another challenge of the detection subsystem included inability to detect enough of

the IR LED’s signal due to factors like distance, noise, and attenuation. It was found that the

phototransistor of the detection subsystem circuit needs to be parallel and upside down to the IR LED of

the waveform generating circuit. The distance at which a distinguishable signal is detected was found to

be about 1-2 cm. The next challenge that was faced was the attenuation of voltage signal when

measuring voltage output values using an oscilloscope. The attempts to create an amplifier circuit were

tried but were unsuccessful.

Regarding the active bandpass filters, a couple approaches were initially explored. One of these

approaches included using a single narrow active bandpass filter, whose schematic is seen in Figure 26

below. The problem faced with this approach was that we had trouble obtaining any kind of output that

resembled a stable waveform as seen in Figure 27 below despite calculating the specific components to

use. The yellow waveform seen is the filters input from a function generator and the blue waveform seen

is the filters output. The bandwidth used in this test was 34-42kHz with a center frequency of 38kHz but

even at the center frequency, the output of the filter had an amplitude of about 60mV despite being

supplied with 5V.

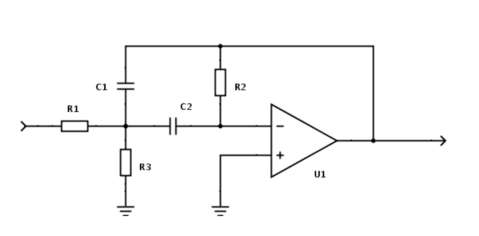
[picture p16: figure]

Figure 26. Initial single narrow bandpass filter circuit tested.

Figure 27. Initial testing of single narrow bandpass filter.

Following this approach, we tested a bandpass filter that consisted of two separate narrow bandpass

filters cascading to each other known as a wide bandpass filter to distinguish between the high-pass filter

and the low-pass filter as seen in Figure 28 below. The bandwidth used in this test was 14-22kHz with a

center frequency of 18kHz but even at the center frequency, the output of the filter had an amplitude of

about 1V despite being supplied with 5V. With this system some type of filter output waveform was

achieved but it had a lot of noise and there was no significant amplification of voltage at frequencies

within the bandwidth or attenuation of voltage at frequencies outside of the bandwidth.

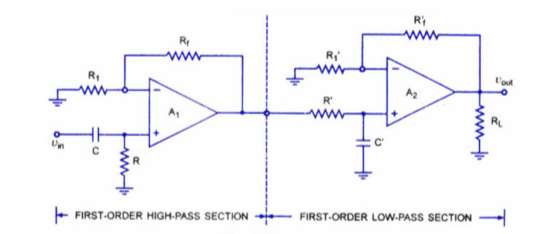
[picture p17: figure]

Figure 28. Wide bandpass filter schematic.

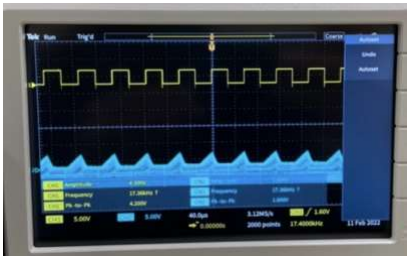
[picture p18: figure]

Figure 29. Testing of wide bandpass filter.

Taking these tests into consideration, we decided to run trial and error tests with different resistor values

to find what would work best. We did this because despite simulating our circuits beforehand and

checking that they worked, that did not translate to the physical circuits. This led to the current

functioning 14-22kHz bandpass filter as we obtained the following waveforms and results through

testing.

Figure 30. 14-22kHz bandpass filter output with 10kHz input.

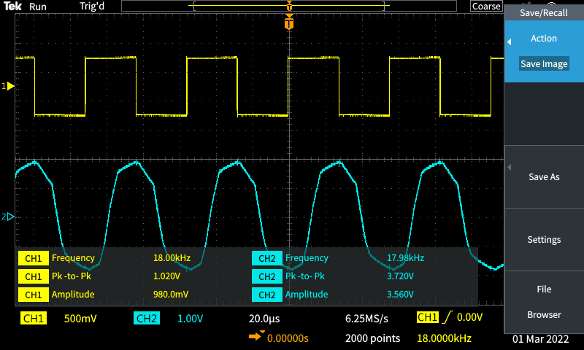
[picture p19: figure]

Figure 31. 14-22kHz bandpass filter output with 18kHz input.

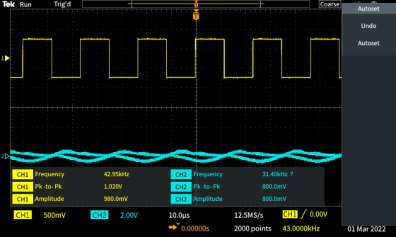
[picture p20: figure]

Figure 32. 14-22kHz bandpass filter output with 30kHz input.

As seen in Figure 31 a more defined and amplified signal was achieved at the center frequency

compared to previous tests and the voltage of the filter output was attenuated at frequencies outside of

the bandwidth as seen in Figure 30 and Figure 32 above. However, despite the positive progress made,

the bandwidth of the system was larger than what was calculated as attenuation of voltage was only seen

around 10kHz and 40kHz compared to the expected frequencies of 14kHz and 22kHz. This was later

improved on in the final filter design by reducing the resistance of R1_S1 and increasing the resistance

of R1_S2 in Figure 8.

7.4 Vendors and facilities used

Part | Unit | Price/Unit | Vendor | Contact
| | | | Information
Ceramic Capacitor Assortment Kit | 1 | $16.99 | Amazon | https://www.amaz
| | | | on.com/

Resistor

Assortment Kit

| 1 | $12.99 | Amazon | https://www.amaz
| | | | on.com/
NE555P Timers | 12 | $0.79 | Amazon | https://www.amaz
| | | | on.c
| | | | https://www.amaz
| | | | on.com/ om/
Operational Amplifier Dual Op-amps | 50 | $0.13 | Amazon | https://www.amaz
| | | | on.com/
Soldering Kit | 1 | $7.48 | Amazon | https://www.amaz
| | | | on.com/
Soldering Board | 1 | $7.98 | Amazon | https://www.amaz
| | | | on.com/
Soldering Putty | 1 | $2.13 | Amazon | https://www.amaz
| | | | on.com/
Potentiometers | | $8.49 | Amazon | https://www.amaz
| | | | on.com/
Multiplexer Breakout Board | 1 | $5.29 | Amazon | https://www.amaz
| | | | on.com/
Multiplexers | 10 | $1.34 | Mouser
| | | Electronics | 1 (800) 346-6873

Considering this project entailed a great deal of testing, our group contacted the Electrical Engineering

Department, and we were able to get access to the electrical engineering lab. Thus, testing was

performed at the Electrical Engineering Laboratory at Nedderman Hall.

8. Performance evaluation

8.1 Detailed description of the testing procedures/protocols for determining the physical and functional

characteristics of the final prototype

There were two physical specifications for this device: The device should be lightweight and not rely on

any external computers. The specification of lightweight was tested by measuring the previous device

and its individual components on a scale, the overall device weighed 373.88g. Then the new components

to be fabricated were weighed by getting a quote on the newly designed PCBs which will an additional

2g. The specification of external sources was resolved through the addition of the waveform generators

and filters. These new additions use an analog system to generate and differentiate different IR LED

frequencies which means it does not rely on external computers to function. However, the system will

rely on an external 9V battery to operate.

The three subsystems that were tested for functional characteristics include waveform generating circuit,

detection subsystem, and the active bandpass filter. Each subsystem has its own breadboard or

perforated board setup as have been shown above.

The waveform generating circuit had a 555 Timer with the following pinout diagram:

Figure 33. The pinout diagram of 555 Timer used in waveform generating circuit.

As can be observed in the above diagram, power supply needed to be connected to pin 8 and pin 1

needed to be grounded. To measure the output of the subsystem after placing resistors and capacitors as

described in the circuit diagram in Figure 4, an oscilloscope was used. Oscilloscope’s pins were

connected to pins 3 and 1. The output would include a square diagram and measurement variables such

as peak to peak voltage and frequency.

The detection subsystem required its own power supply of +5 V and ground pins. The subsystem needed

to have a unique setup to be able to detect any signal and to measure the incoming signal. The setup of

the detection system and waveform generating circuit are represented in the following figure:

Figure 34. The setup of detection subsystem and waveform generating circuit.

As can be observed from the above setup, where the top breadboard is the detection subsystem with a

phototransistor having yellow and black wires that are extended towards SMD model IR LED. The

bottom breadboard is the waveform generating circuit where red and black wires that are connected to

SMD model IR LED which is placed right below the upside down SMD model phototransistor

component. To measure the output signal of the phototransistor oscilloscope was used to plot the

obtained signal. Two pins of oscilloscope were connected to the positive pin of the phototransistor and

ground. Oscilloscope was used to plot signal as well as obtain measurements such as voltage peak to

peak and frequency values. On some occasions when the output of the detection signal was not clear or

hard to analyze, Arduino Uno was used to plot the obtained signal.

The active bandpass filter utilized a dual op-amp with the following pin configuration:

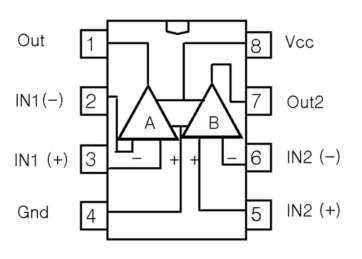
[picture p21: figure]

Figure 35. The pinout diagram of dual op-amp used in the active bandpass filter circuit.

The configuration of the dual op-amp pins can be seen in the schematic diagram of the active bandpass

filter in Figure 8. However, to test the subsystem, 3-5V were supplied to circuit through pin 8 and the

output of the filter was visualized on an oscilloscope connected to pin 7 of the op-amp. Initial testing of

the individual subsystem utilized a waveform generator to mimic the function of the waveform

generating circuit being designed. The waveform generator was used to supply signals at various

frequencies to observe how the 14-22kHz bandpass filter reacted to those frequencies by measuring the

change in voltage and calculating the frequency response of the system.

The three subsystems that were worked on independently were finally combined to test the combination

of all subsystems. Ideally, this combination of three subsystems would have become the basis of the

fingernail and ring system.

The setup of all subsystems included setting the waveform generating circuit with the correct targeted

frequency with detection system and connecting the output of the detection system to the active

bandpass filter.

The top breadboard in the below figure represents the three different target frequencies achieved by

building three waveform generating circuits on the big breadboard. These target frequencies were 10

kHz, 18 kHz, and 30 kHz. The SMD model phototransistor on the detection system was upside down

and was placed right above the SMD model IR LED to achieve the data acquisition by phototransistor.

The output of the detection system was fed to the 14-22 kHz active bandpass filter which had a central

frequency equal to 18 kHz.

The three subsystems each required their own voltage supply and oscilloscope wires to plot the three

output signals from waveform generating circuit, detection system, and 14-22 kHz active bandpass filter.

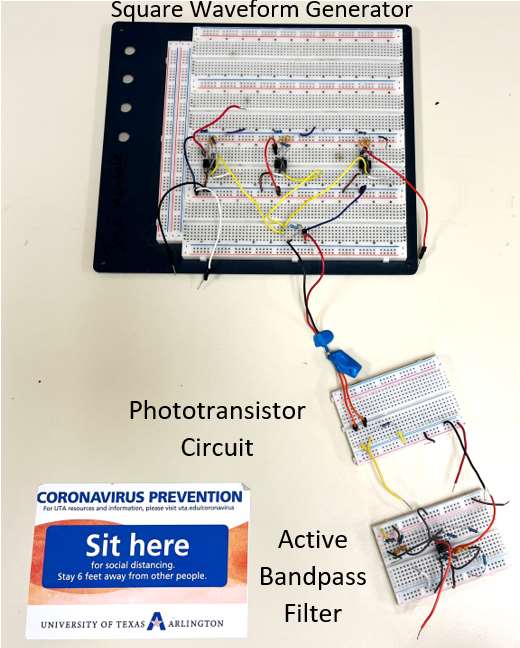
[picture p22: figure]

Figure 36. Three subsystems set-up and tested together.

8.2 Results from the performance evaluation tests

The testing procedures of the three subsystems were carried out using multimeter and oscilloscope.

Multimeter was used to double check the resistor values and the oscilloscope was utilized to plot the

signals and analyze the obtained graphs.

The following graph shows the signals from 38 kHz waveform generating signal and the phototransistor

circuits. The signals were plotted on the oscilloscope and the measurements were obtained as well:

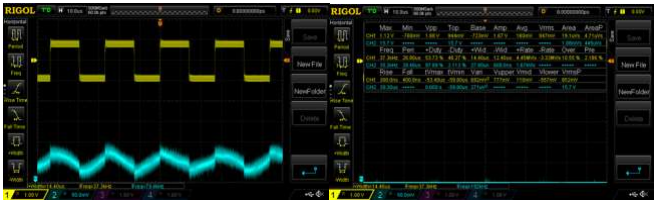
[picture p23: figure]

Figure 37. Plotted output signals of the waveform generating circuit and detection subsystem.

In the above Figures, the yellow line represents the output signal of 38 kHz waveform generating circuit

and the blue line stands for the output signal of the detection subsystem. The setup of these subsystems

is like Figure 34.

For the 14-22kHz bandpass filter, as mentioned before, the main objective during testing was to record

the change in output voltage of the filter at a range of frequencies to identify whether the filter was

accepting and rejecting the desired frequencies. These results are seen in Table 10, Figure 16 and Figure

17, where the change in input and output voltage of the filter was recorded.

8.2.1 Embed video or photos of the evaluation process

The video was uploaded on YouTube and a brief description can be provided.

Video 1 shows the testing of our 3 subsystems in their breadboard's models. The three subsystems

include an 18 kHz waveform generating subsystem, detection subsystem, and filter. These subsystems’

breadboards were connected to power sources as well as oscilloscopes to measure the output signals.

The first oscilloscope shows the square waves from 10 kHz,18 kHz or 30 kHz waveform generating

circuit in yellow lines and blue lines that are the signal output of the detection subsystem. The second

oscilloscope shows the response of the 14-22 kHz active bandpass filter.

Video 2 shows demonstration of fabricated subsystems on perforated boards. Those subsystems are an

18 kHz waveform generating circuit and 14-22 kHz active bandpass filter. The 18 kHz waveform

generating circuit shows square waves on the oscilloscope with an approximate measured frequency of

19.34 kHz shown on the screen of the oscilloscope. The demonstration of 14-22 kHz active bandpass

filter included showing the signal output at 3 specific frequencies that were supplied to the circuit by the

function generator. The yellow line which corresponds to Channel 1 of the oscilloscope provides the visual representation of the function generator’s function. The blue line corresponds to Channel 2 of the

oscilloscope and provides output signal of the 14-22 kHz active bandpass filter. The first supplied

frequency of 10 kHz resulted in very attenuated signal output. The second supplied frequency of 18 kHz

resulted in less attenuated output and the signal has a more defined shape. The third supplied frequency

of 30 kHz resulted in another attenuated signal output of the filter.

Video 3 shows three different testing that were performed. In the first and second testing setups

detection system had phototransistor receiving some type of infrared light signal and the output of the

phototransistor was fed to the 14-22 kHz active bandpass filter and the output of the filter was plotted. In

the first setup, modulated IR LED was shone at the phototransistor at 18 kHz rate and the output of the

phototransistor was fed to the 14-22 kHz active bandpass filter. The outputs plotted on the first shown

oscilloscope included the yellow lined output of the waveform generator that made the IR LED shine at

18 kHz in a form of square waves and the blue lined output represents the output of the phototransistor.

The second oscilloscope shows the output of the 14-22 kHz active bandpass filter. The second testing

setup included shining unmodulated IR LED onto the phototransistor and this setup involves shining an

IR LED at close proximity to the phototransistor. All three outputs were shown like the first setup. The

third testing setup included feeding DC offset signal with a frequency of 0.1 mHz to the 14-22 kHz

active bandpass filter and observing the output signal of the 14-22 kHz active bandpass filter.

The following are the videos to evaluate the process:

[Video1] Light Weight ASL Translation Device (https://youtu.be/NsMCEhbKllM)

[Video 2] Perforated Board Components Demonstration (https://youtu.be/dqh3HnOIT4E)

[Video 3] System Demonstration (https://youtu.be/ejmzKrtcBgY)

8.2.2 Show quantitative results obtained from the performance evaluation tests

Quantitative results related to the three subsystems were obtained using oscilloscope. Attempts were

made to obtain quantitative results from simulation tools NI Multisim and Arduino Uno but were

unsuccessful. The following representation was obtained after performing a successful testing of all

three subsystems:

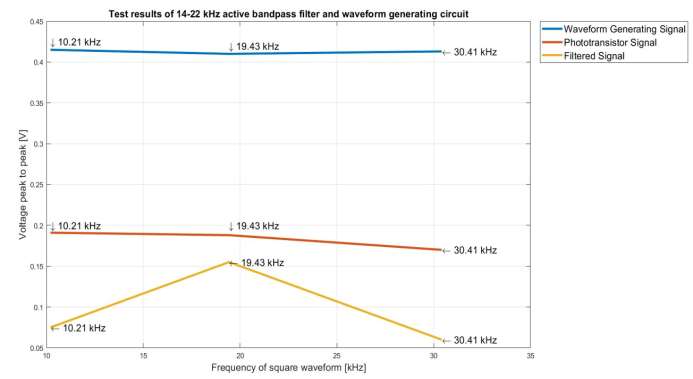
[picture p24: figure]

Figure 38. Test results of three subsystems: waveform generating circuit, detection subsystem, filter.

As can be observed from the above figure, three waveform generating circuits were built with the

following unique frequencies: 10 kHz, 18 kHz, and 30 kHz. Oscilloscope was used to obtain the exact

frequencies which were labeled on the graph. The correct measurements of the unique frequencies were

measured to be 10.2 kHz, 19.4 kHz, and 30.4 kHz.

The detection subsystem was set up to detect signals from the IR LED that was powered by the

waveform generating circuits and had the output described by the orange line in the above graph.

The 14-22 kHz active bandpass filter was set up to use the output signal of the phototransistor as the

input signal for the filter and the output was plotted above in the blue line. The following values can be

used as reference for the above graph:

Table 14. The quantitative results of testing three following subsystems: waveform generating circuits,

detection subsystem, 14-22 kHz active bandpass filter

Frequency [kHz] | Vout Waveform
| Generating Circuit [V] | Vout Detection
| | subsystem [V] | Vout 14-22 kHz Active
| | | Bandpass Filter [V]
10.2 | 0.415 | 0.191 | 0.075
19.4 | 0.410 | 0.188 | 0.155
30.4 | 0.413 | 0.170 | 0.06

8.3 Analysis of test results

The three subsystems were set up to obtain results of the testing that involved testing all subsystems.

The three unique frequencies that were tested were 10 kHz, 18 kHz, and 30 kHz that were produced by

three waveform generating circuits. Each waveform generating circuit was set up for the detection

subsystem to record the output signal of the IR LED by phototransistor. The 14-22 kHz active bandpass

filter was used to test the ability of the circuit to filter out the unnecessary and out of bandwidth

frequencies such as 10 kHz and 30 kHz.

The waveform generating circuits were able to produce frequencies that were close to the target

frequencies. The 10 kHz waveform generating circuit produced a frequency that was only 0.21 kHz off

from the target frequency. The 18 kHz waveform generating circuit produced a frequency that was only

1.43 kHz off from the target frequency. The 30 kHz waveform generating circuit produced a frequency

that was only 0.41 kHz off from the target frequency. The detected frequencies and the square

waveforms that were produced by the circuit were stable and fixed. The voltage output of these circuits

was the highest among the three subsystems but were still small to continue our project.

The detection subsystem was able to detect some signal emitted by the IR LED and the output signal of

the subsystem was plotted after obtaining voltage peak to peak values. The voltage values were quite

attenuated, and the detection signal did not represent any shape but ideally should have represented

somewhat square waveform shape like the waveform generating circuit’s square waveform.

The 14-22kHz filter was able to accept and reject the desired frequencies, however, the voltage output of

the subsystem while connected to the entire system was extremely low compared to the individual

subsystem testing seen in Figure 16. The highest voltage output achieved was approximately 0.155V close to the center frequency of 18kHz as seen in Figure 38, and the voltage did attenuate as the input

frequency changed between 10kHz and 30kHz to approximately 0.075V and 0.06V, respectively.

8.3.1. Quantitative comparison with physical specifications

The previously defined physical specifications were tested and compared to the final device. We defined

that the device should be lightweight and not weigh more than 400 g. We measured the previous device

and found the wrist CPU weighed 350.43g, the fingernails weighed 12.7g, and the rings weighed 10.7g,

meaning the overall device weighed 373.88g. The addition of the waveform generators and filters will

add a weight of 2g making the overall device weigh 375.88g. We also defined the device should not rely

on any external computers. The device does not rely on any external sources due to the incorporation of

a speaker, LCD screen, waveform generator and filters. However, the power supply to the device is an

issue, as it cannot function on its own, which is why an external battery source is needed. The battery

used is a 9V power bank battery which can be clipped on around the waist.

8.3.2 Quantitative comparison with functional specifications

Three subsystems that were developed and tested included being powered by the voltage supply in the

laboratory settings. It is known that the whole device that originally was thought to be built utilizes 5 V

maximum voltage and one of the main aspects of the testing was to keep all the power supply at

maximum 5 V.

The waveform generating circuit utilized 5 V and the main component of the circuit to get powered was

the IR LED. Due to the way the circuit was built with resistors and capacitors, the IR LED received less

than 5 V and thus the IR LED blinked at a smaller intensity. The frequency with which it blinked

matched the desired frequency. The target frequencies that were set by the team and mentors work well

with the overall system and the transponders within ring and fingernail devices.

The detection subsystem utilized 5V power supply and due to the nature of the SMD model

phototransistor, the component received less than 5 V and the output signal depended on how strong the

IR LED was blinking. Due to the low intensity of the IR LED, the output voltage of the phototransistor

was low as well.

Similarly, the 14-22kHz bandpass filter was supplied with 5V to ensure it would function well with the

entire system. Despite this, a lot of voltage was lost due to the number of resistors implemented into the

wide bandpass filter design. This decreased power supply to the circuit also resulted in a lower voltage

output and gain of the filter resulting in less amplification of signals at desired frequencies.

The waveform generating circuit, detection subsystem and filter subsystem utilized 5V, but output

voltage was lower than expected. Low voltage will be a challenge for the whole device because Arduino

Mega may not be able to work well with such low inputs.

8.4 Needed modifications that were applied to the design/prototype to achieve design specifications

The three subsystems that were developed had multiple prototypes and some were successful. The three

subsystems included waveform generating circuit, detection subsystem, and active bandpass filter. Aside

from the three subsystems, amplifier circuits were attempted but due to lack of time, the group did not

pursue to make the amplifier circuits work.

Waveform generating circuit that was initially built which can be observed on the Figure 9 was very

unstable in terms of the frequency of the generated waveform and it was hard to work with such

subsystem. Troubleshooting and research gave some ideas that were pursued by the group and a new

design utilizing specific component values was simulated on the NI Multisim to see how it works.

The detection subsystem operates by having a phototransistor detect infrared light emitted by the IR

LED. The initial prototypes of the circuit were outputting extremely low voltage values.

Troubleshooting with the group's mentor was then done which included testing of higher and lower

resistor values in the detection system to observe the difference in voltage output.

As mentioned earlier, multiple approaches were taken when designing the active bandpass filter. Once

the final design was achieved, the issues faced involved low voltage output and a wider bandwidth range

than desired. To address these issues, we made modifications to the subsystem's components,

specifically the resistors as mentioned above and explored other components to implement.

8.4.1 Show how the modifications improved the performance of the prototype

As mentioned above, a new waveform generating circuit was simulated and following the simulation,

the new circuit was built on a breadboard and further testing showed a more stable waveform and the

frequency was not fluctuating as much, staying within 18-19kHz for this system. This helped with

ensuring that the IR LED was modulated at a more accurate frequency resulting in a more accurate

system as the bandpass filter would be able to filter out more of that frequency as it is the center

frequency of the filter.

After troubleshooting the detection system with the group’s mentor, the testing showed that the voltage

output increased after increasing the value of the resistor used in the detection subsystem’s circuit. It

was decided to use 1 MΩ resistor for the circuit to obtain maximum voltage output from the detection subsystem. Similarly, this improved the system by providing the signal sent to the filter with the highest

voltage possible making visualization of voltage amplification or attenuation by the filter easier to

identify.

The modifications made to the filter mentioned above helped decrease the bandwidth closer to the

desired range of 14-22kHz making filtering of specific frequencies slightly more accurate. However, the

modifications did not have much of an impact on the voltage output of the subsystem, hence the

suggestion of implementing an amplifier circuit or voltage regulator to future systems as low voltage

outputs were still being recorded.

8.5 Assessment of the prototype performance based on the results of the performance tests

Given that the team was pushed to change the direction of the project midway through the year, and

work on replacing the previous filtering system with a new analog system, a completely new plan

needed to be decided. Thoroughly researching the new system gave the team a delayed start to the

project than we had hoped for. After much testing and troubleshooting, one of the subsystems that was

worked on, the square wave generator, yielded successful results. However, the bandpass filter system

still needs some improvements as does the amplifier circuit. Given the short amount of working time the

team had, we were still able to provide an insight as to whether this direction would benefit the future of

the device. We believe the testing and troubleshooting done will set a solid foundation for future

generations to build upon and improve the functionality of the current device.

8.6 Assessment of environmental impact and sustainability standards of the project

After thoroughly assessing the environmental and the sustainability standards of our project, we have

concluded that we met the proper standards that were set early on. All soldering was done in a well-

ventilated lab with a fume extractor to eliminate any toxic fumes from the soldering process. All waste

materials were properly disposed of in a safe manner in the correct facilities.

9. Summary and recommendation for future improvements

After thorough research and testing, the 9th generation of the American Sign Language Translation

Device team decided that it was best for the progress of the device to switch from the previous digital

filtering system to an analog filtering system. While the digital system worked and served its purpose of

filtering some frequencies, the device still had trouble recognizing different frequencies thus it was

having many errors when translating. Due to the advice of our mentor, the team decided an analog

filtering system would solve this issue. We also are hopeful the new system will be able to trigger the fingernail devices, which have been an issue with the overall device for many years. We were able to

build and miniaturize a 14-22 kHz active bandpass filter, an 18 kHz waveform generator circuit and a

detection circuit. We were also able to build a 34-42 kHz bandpass filter, but we were not able to

miniaturize it. For the future progression of the project, we would recommend the following: replacing

the battery, modifying the active bandpass filters, continuing to build on the amplifier circuit,

redesigning the ring and fingernail components, updating the python script, and adding regulators to the

op-amp circuit. For the battery replacement, we recommend the 9V power bank be replaced with two

18650 batteries in series. The current battery weighs 187.11g and has a 600mAh capacity so it would

only give us 1 hour of battery life. The two 18650 batteries replacement would weigh 90g having a total

of 7.4v with 3500mAh capacity which means 5.83 hours of battery life. The modification of the active

bandpass would entail shortening the bandwidth range, filtering the out-of-bandwidth frequencies, and

amplifying the in-bandwidth frequencies. To continue to build on the amplifier circuit we would

recommend further researching the properties of the circuit and simulating and testing the circuit to have

an amplified voltage output. To incorporate the new PCBs, we will have to adjust the design of the ring

and fingernail components to fit them. The python script for the device will need to be updated. The

UTF-8 error needs to be fixed, the reset button code requires debugging, and the FFT portion will need

to be removed as it is not a part of the system anymore. Finally, we suggest adding a regulator to the op-

amp circuit to maintain the 0-5 V voltage range within the feedback loop so that the circuit does not

burn out.

10. Team members’ contributions
10.1. Author for each section of the report

Author | Section
Ruqaya Abdulzahraa | 2.0 Executive Summary 4.5 A brief outline of how this written report is organized 5.4 Cost Constraints
5.5. Project duration constraints
6.5. Assessment of chances of success
7.4. A complete list of all parts
8.5. Assessment of the prototype performance
| based on the results of the performance tests
8.6. Assessment of environmental impact and
| sustainability of the project
9. Summary and Recommendation for Future
| Improvements
Savannah Chiweshe | 5.1. Detailed quantitative functional specifications
6.1. Description of the selected design concept and
| rationale behind it
6.2. Description of the major subsystems
| 6.2.1 Drawings, Schematics, and Other
6.3. Engineering design computations
6.4. Simulation results
7.1. Details of how the device prototype was
| fabricated
7.2. Figures, photos, and other forms of
| illustrations of the device
7.3. Modifications to the design that were needed to
| achieve the design specifications
8.1. Detailed description of the testing
| procedures/protocols for determining the physical and functional characteristics of the final prototype
8.2. Results from the performance evaluation tests

8.3 Analysis of test results

8.3.2. Quantitative comparison with functional

specifications

8.4. Needed modifications that were applied to the

design/prototype to achieve design specifications

8.4.1 Show how the Modifications Improved

Performance of the Prototype

8.5. Assessment of the prototype performance

based on the results of the performance tests

9. Summary and Recommendation for Future

Improvements

Mahri Kadyrova | 3. Table of Contents
4.2. Existing Similar systems
5.1. Detailed quantitative functional specifications
6.1. Description of the selected design concept and
| rationale behind it
6.2. Description of the major subsystems
| 6.2.1 Drawings, Schematics, and Other Illustrative means of Showing System and Subsystems for the Device
6.3. Engineering design computations
6.4. Simulation results
6.5. Assessment of chances of success
7.1. Details of how the device prototype was
| fabricated
7.2. Figures, photos, and other forms of
| illustrations of the device
7.3. Modifications to the design that were needed to
| achieve the design specifications
8.1. Detailed description of the testing
| procedures/protocols for determining the physical and functional characteristics of the final prototype

8.2. Results from the performance evaluation tests
8.2.1. Embedded video or photos of the evaluation

process

8.2.2 Show Quantitative Results Obtained from the

Performance Evaluation Tests

8.3 Analysis of test results

8.3.2. Quantitative comparison with functional

specifications

8.4. Needed modifications that were applied to the

design/prototype to achieve design specifications

9. Summary and Recommendation for Future

Improvements

Ridhaa Shariff | 1. Title Page 2.0 Executive Summary
4.1. Significance and benefits of the project
4.3. Objectives of the project
4.4. Distinguishing features of the proposed system
| compared to existing similar systems 5.0 Project Specifications
5.2. Detailed quantitative physical specifications
5.3. Engineering, safety, environmental, and
| sustainability standards
5.6. Final project schedule
8.1. Detailed description of the testing
| procedures/protocols for determining the physical and functional characteristics of the final prototype
8.3.1. Quantitative comparison with physical
| specifications
9. Summary and Recommendation for Future
| Improvements
10. Team Members Contributions
| 11.0 Acknowledgements

10.2 Main contributors for project aspects

Contributor | Aspect
Ruqaya Abdulzahraa | Researching Previous Device Ordering Parts Researching Alternative Routes Creating and Organizing Presentations for Class Leading Innovation Day Preparation Creating Innovation Day Poster
Savannah Chiweshe | Bandpass Filters Research Bandpass Filters Simulation Bandpass Filters Construction and Fabrication Troubleshooting Systems Creating Innovation Day Poster
Mahri Kadyrova | Waveform Generator Research Waveform Generator Simulation Waveform Generator Construction and Fabrication NI Multisim Simulation Troubleshooting Systems Creating Innovation Day Poster
Ridhaa Shariff | Researching Alternative Routes Learning and Executing Soldering Eagle PCB Designing Creating and Organizing Presentations for Class Leading Innovation Day Preparation Creating Innovation Day Poster
11. Acknowledgements

11.1 Acknowledge the people who assisted your team in completing the project

We would like to thank Dr. Oguz Yetkin and Dr. Khosrow Behbehani for their guidance and feedback

throughout the progression of the project. We would like to specifically thank Dr. Christopher

McMurrough and Dr. Adam Atticus Argersinger for providing us with access to the electrical

engineering labs. We would also like to thank Dr. Greg Turner for providing us with access to NI

Multisim software. We would also like to thank the previous generations who worked device for their

contribution to the project and for continuing to assist in the development of the project. We would also

like to thank the Biomedical Engineering Department at The University of Texas at Arlington for this

opportunity and facilities to ensure the success of this project.

12. Appendix

Previous Gantt Chart:

Previous PERT Diagram:

13.References

1. “Deafness and Hearing Loss.” World Health Organization, World Health Organization,

https://www.who.int/news-room/fact-sheets/detail/deafness-and-hearing-

loss#:~:text=Over%205%25%20of%20the%20world's,will%20have%20disabling%20hearing%20loss. (https://www.who.int/news-room/fact-sheets/detail/deafness-and-hearing-loss)

2. Demographics –. (2021, January 12). Gallaudet University. https://www.gallaudet.edu/office-

ofinternational-affairs/demographics/deaf-employment-reports/ (https://www.gallaudet.edu/office-ofinternational-affairs/demographics/deaf-employment-reports/)

3. Mitchell, R. E. (2005). How Many Deaf People Are There in the United States? Estimates From the

Survey of Income and Program Participation. Journal of Deaf Studies and Deaf Education,

11(1), 112–119. https://doi.org/10.1093/deafed/enj004

4. Davies, J. (2021, November 18). ‘Second-class citizens:’ Hard-of-hearing employees frustrated by

lack of accessibility in remote and hybrid working. Digiday. https://digiday.com/media/second-class-

citizens-hard-of-hearing-employees-frustrated-by-lack-of-accessibility-in-remote-and-hybrid-working/ (https://digiday.com/media/second-class-citizens-hard-of-hearing-employees-frustrated-by-lack-of-accessibility-in-remote-and-hybrid-working/)

5. Lempka, C. (2019). Employees Who are Deaf or Hard of Hearing: Perceptions of Workplace

Accommodations. Ursidae: The Undergraduate Research Journal at the University of Northern

Colorado, 5(2).

6. Lin, M. R. V. (2010). ECE 4760 Sign Language Glove. Copyright (c) 2013 Monica Lin, Roberto

Villalba.

https://people.ece.cornell.edu/land/courses/ece4760/FinalProjects/f2014/rdv28_mjl256/webpage/

7. DeepASL: Enabling Ubiquitous and Non-Intrusive Word and Sentence-Level Sign Language

Translation. (2017). Proceedings of SenSys ’17. Published.

8. Safety of Laser Products - Part 9: Compilation of Maximum Permissible Exposure to Incoherent

Optical Radiation (IEC/TR 60825–9). (1999, October).

9. WORKER DEATHS BY ELECTROCUTION A Summary of NIOSH Surveillance and

Investigative Findings (No. 98–131). (1998, May). U.S. DEPARTMENT OF HEALTH AND

HUMAN SERVICES.

10. Lead Soldering Safety. (2022). UC San Diego. https://blink.ucsd.edu/safety/occupational/hazard-

control/lead- (https://blink.ucsd.edu/safety/occupational/hazard-control/lead-soldering.html)

soldering.html#:%7E:text=Soldering%20with%20lead%20(or%20other,and%20upper%20respiratory%

20tract%20irritation. (https://blink.ucsd.edu/safety/occupational/hazard-control/lead-soldering.html)

11. Lead Solder. (2018, May 7). Environment, Health and Safety.

https://ehs.unc.edu/environmental/fact-sheets/lead-solder/

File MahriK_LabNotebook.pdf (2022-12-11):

Mahri Kadyrova

Mahri Kadyrova

BE 4355

Senior Design II

Notebook #1-2-3-4-5

Table of Contents

Contents

April 7th

April 10th

April 12th

April 25th

January 18th Senior Design Task
Objective: Building adjustable square wave generator circuit with a 555 timer

Approach for activity: Learn about 555 timer as much as possible

Outcome of activity: Found one circuit to try out later

Impact of activity on the project: Very important with waveform generator task

Assessment of the importance of activity: Important in continuing the project

Tips to improve the approach for doing the activity for iterations: Find the datasheet first

555 Timer Pins

fc=

1.44
(R1+R2)∗C

Example:

- R1= 100Ω
- R2=100 Ω
- C1=0.15 uF
- fc=48 kHz

1: Ground

2: Trigger

3: Output

4: Reset

8: Power Supply

7:Discharge

6: Threshold

5:Control Voltage

Circuit 1 connections; 1: Ground; 2: Trigger; 3: Output; 4: Reset; 8: Power Supply; 7:Discharge; 6: Threshold; 5:Control Voltage

January 19th Senior Design Task
Objective: Building adjustable square wave generator circuit with a 555 timer

Approach for activity: Find the right circuit and try to copy it

Outcome of activity: Circuit was found and created

Impact of activity on the project: Important in completion of the waveform generator task

Assessment of the importance of activity: Very important to continue the project

Tips to improve the approach for doing the activity for iterations: Find datasheet first next time

Datasheet has the formulas for astable waveforms

- Pin 3 : output and ground for oscilloscope channel 1
- Capacitor and ground (?) for oscilloscope channel 2
- Multimeter to measure capacitance values
- Pin 5 to ground to reduce noise
- 0.01 uF capacitor
- Pin 4: connected to voltage
- Potentiometer instead of Rb resistor
- Pin 6 and 7
- Pin 6 to middle pin of potentiometer
- Pin 7 to resistor Ra and that resistor to upper potentiometer pin
- Circuit to create:

555 timer tutorial

- Pin 1 to ground

- Pin 2 to Pin 6
- Pin 3 to resistor for LED resistor Rl
- Connect LED to that resistor in series
- Resistor in series and to ground
- Pin 4 to positive voltage pin
- Pin 5 to nothing
- Pin 6 to resistor Rb
- Rb to pin 7
- Pin 7 to resistor Ra
- Resistor Ra to positive voltage source pin
- Pin 8 to positive voltage source

Without capacitor LED doesn’t do anything

Capacitor:

- Negative side to the negative voltage source (aka ground)
- Positive side of capacitor to pin 2

LED will start blinking with capacitor.

Adjustable flashing/blinking LED

555 timer across the breadboard:

- Pin 1 to negative voltage source
- Pin 8 to positive voltage source
- Pin 6 to pin 2
- Pin 4 to pin 8
- Pin 7 and pin 8 to Ra=1 kΩ
- Pin 6 and pin 7 to Rb=100 kΩ
- Capacitor C1= 10uF
- Pin 1 to negative capacitor pin
- Pin 2 to positive capacitor pin
- Extend pin 3 with jumper wire and put the LED in series with the jumper wire and the resistor Rl=220 Ω. Connect them to negative voltage source (aka ground)
- ↓resistance value flashing rate/blinking increases
- ↓ capacitor value flashing rate/ blinking increases

Low Frequency Pulse Generator Circuit

↑R1 ↓F

↑C1 ↓F

f=1/TC

f =

1.44
(R1 + 2 ∗ R2) ∗ C

Practice


Created circuit:

Frequency generated: 8Hz

January 20th Senior Design Task
Objective: Building adjustable square wave generator circuit with a 555 timer

Approach for activity: Build circuits and test for correctness

Outcome of activity: Oscilloscope square waveform was generated

Impact of activity on the project: Important in progress of waveform generator task

Assessment of the importance of activity: Very important in continuing project

TC
Pulse
width

Tips to improve the approach for doing the activity for iterations: Find the datasheet next time

Practice

Created circuit:


Oscilloscope results:

Created circuit:

Oscilloscope results:


1 Hz Pulse Frequency Generator with 555 Timer

Circuit connections of 555 timer:

- Pin 1 to ground
- Pin 3 connected to R2 = 220 Ω and that resistor connected to LED in series
- Pin 5 to C2=10nF
- C2 to ground
- Pin 2 connects to VR=100 kΩ
- Pin 7 connects to R1=10 kΩ

- Pin 4 connects to R1=10kΩ
- Pin 8 connects to positive voltage source (+9V)
- Circuit Diagram:

IC- integrated circuit

- 555 timer IC
- Oscillating circuit
- Astable
- Pin 3- output: is where oscillations are
- Astable mode voltage circuit:
1: Ground | 8: Power Supply

Notes:; January 21; st Senior Design Task; 2: Trigger; 3: Output; 4: Reset

- Rl has to be larger when using bigger voltage source.

Objective: Building adjustable square wave generator circuit with a 555 timer

Approach for activity: To build circuits from tutorials and make sure components work

Outcome of activity: Circuit and square waveform was generated

Impact of activity on the project: Important in progress of the waveform generator task

Assessment of the importance of activity: very important to continue the project

Tips to improve the approach for doing the activity for iterations: Find the Datasheet first next time

Practice

Created circuit:

Connections on breadboard:

- Pin 8-7: Ra=100 kΩ
- Pin 7-6: Rb=100 kΩ
- Pin 6-GND: C=1nF
- Pin 3 connected to resistor Rl= 330 Ω which is in series connected to LED and ground

Measuring resistors using multimeter

Connections on breadboard

- RL=230 Ω
- Pin 8-7 resistor Ra=106 kΩ
- Pin 7-6 resistor Rb=100 kΩ
- Pin 3 reading:
- Peak to peak : 3.92-4.16 V [fluctuates]
- Frequency ~ 1.3 kHz
- RMS ~ 9.16 mV

New Circuit Diagram from Texas Instruments Datasheet

Connections on breadboard:

- Pin 1 to ground
- Pin to pin 6
- Pin 2 to capacitor C1

- Capacitor C1 to ground
- Resistor Rb to pin 6 and pin 7
- Resistor Ra to pin 7 and pin 8
- Pin 4 to pin 8
- Pin 5 to nothing
- Pin 4 to C 2= 0.01 uF
- C2 connected to pin 4 and then to ground
- Pin 8 to 5 V voltage source
- Rl connects pin 3 and pin 8

Experiment test

Findings include:

- Ra= 5.1 kΩ
- Rb= 3 kΩ
- C1=0.15 uF
- Rl=1 kΩ
- Oscilloscope results :

- Circuit created :


Testing with C1= 10pF

New components include:
- C1=10 pF
- Ra=5.1 kΩ
- Rb= 3kΩ

Calculated frequency using above formulas: 12,972 kHz

Oscilloscope given frequency: 214.279 kHz

Oscilloscope square waveforms:

January 25st Senior Design Task
Objective: Generating 38 kHz oscillator

Approach for activity: Use the circuit diagram from Texas Instruments Datasheet for NE555+ timer

Outcome of activity: 2 circuits have been generated with 38 kHz and 56 kHz

Impact of activity on the project: Helped progress on the waveform generator task

Assessment of the importance of activity: Very important to see if the waveform generator is possible

Tips to improve the approach for doing the activity for iterations: Next time use multimeter for all the components to acquire as accurate resistor values as possible

Experimenting with previous circuit

Rl= 1 kΩ

C2=0.01 uF=10nF

Entry | Ra [connected to pin 8 and pin 7] (kΩ) | Rb [connected to pin 6 and pin 7] (kΩ) | C1 [ changing capacitor value while C2 is set] (nF) | Oscilloscope frequency (kHz) | Calculated frequency [using formula] (kHz)
1 | 5.1 | 3 | 10^(-2) | ~214.8
2 | 5.1 | 3 | 1 | ~ 89.35
3 | 5.1 | 5.1 | 1 | ~70.2
4 | 5.1 | 33 | 1 | ~18.82 | 20.253
5 | 5.1 | 22 | 1 | ~26.3 | 29.327
6 | 5.1 | 15 | 1 | ~35.2 | 41.026
7 | 4.7 | 15 | 1 | ~35.6 | 41.499
8 | 3 | 15 | 1 | ~37.4 | 43.636
9 | 2.2 | 15 | 1 | ~38.2 | 44.720
Table 1

Notes:

- ↓Rb ↑Fosc
- ↓Ra ↑Fosc

Entry from Table 1 | Ratios of Freq calculated/Freq oscilloscope | Difference: Freq calculated – Frew oscilloscope (kHz)
4 | 1.076 | 1.433
5 | 1.115 | 3.027
6 | 1.1655 | 5.826
7 | 1.156 | 5.899
8 | 1.166 | 6.236
9 | 1.17 | 6.52
Table 2

Generating 56 kHz oscillator

Entry Ra (kΩ) Ra from
multimeter
(kΩ)

Rb (kΩ) Rb from
multimeter
(kΩ)
| | | | | C1 (nF) | Freq oscilloscope (kHz)
1 | 5.1 | 5.125 | 5.1 | 5.066 | 1 | ~ 70.8
2 | 5.1 | 5.125 | 5.6 | 5.582 | 1 | ~67.3
3 | 5.1 | 5.125 | 7.5 | 7.429 | 1 | ~57.16
4 | 5.6 | 5.582 | 7.5 | 7.429 | 1 | ~56.12
Table 3

January 31st Senior Design Task
Objective: Learning how to solder to

Approach for activity: Use NH 148A lab to learn how to solder

Outcome of activity: Learned how to use solder wire and solder iron

Impact of activity on the project: Will let us connect header wires to the SMD phototransistor

Assessment of the importance of activity: Very important to take care of our experiments

Tips to improve the approach for doing the activity for iterations: Invite other teammates next time because one person can’t solder header wires onto an SMD component

Tools used:

- Solder iron set at 600 F
- Tip cleaning sponge and metal brass wool
- Tweezers
- Soldering wire
- Soldering practice kit

January 28th Senior Design Task
Objective: Creating the phototransistor-waveform generator circuit

Approach for activity: Creating a phototransistor circuit and putting two circuits together

Outcome of activity: Were able to see some data

Impact of activity on the project: Big impact

Assessment of the importance of activity: Very important

Tips to improve the approach for doing the activity for iterations: Maybe buy a full size phototransistor to experiment with or solder better

I put the phototransistor in series with a resistor with various values. The phototransistor was soldered to two wires and it doesn’t work properly most of the time.

February 2nd Senior Design Task
Objective: Learning op amp to create a hardware filter

Approach for activity: Googled the information

Outcome of activity: Learned a little about the pinout of op amp

Impact of activity on the project: Very big

Assessment of the importance of activity: Quite important

Tips to improve the approach for doing the activity for iterations: Make sure to learn the pinout of the op amp we actually have

The following pinout was studied:

Notes taken:

- We need active bandpass filter and for that we need op amp

February 4th Senior Design Task
Objective: Learning about bandpass filter

Approach for activity: Googling and recreating

Outcome of activity: Learned a little about the concept

Impact of activity on the project: Very important to be completed soon

Assessment of the importance of activity: Important to get completed

Tips to improve the approach for doing the activity for iterations: Maybe reach out to other engineers beforehand

Following was studied:

Active bandpass filter notes:

- Amplifies input signal
- Needs transistors or op amps
- Combination of high and low pass filers

The first filter we need to create:

- f1=35 kHz [low cutoff frequency]
- f2=41 kHz [high cutoff frequency]

Using LM741 op amp notes:

- pin 7 and pin 4 are power pins
- pin 7 gets +DC voltage
- pin 4 gets -DC voltage
- pin 2 and 3 are input pins to op amp
- pin 2 is the inverting terminal
- pin 3 is the noninverting terminal
- pin 6 is the output

Active inverting op amp bandpass filter circuit notes: [insert the circuit]

- op amps needs DC power
- output AC voltage signal will only be as high as ceiling and floor
- pin 4 is connected to negative voltage and cant be connected to ground
- pin 7 is connected to positive voltage
- High pass filter:
- R1 and C1 are responsible for it
- Passes all frequencies above the point is it desifned to pass
- Creates lower cutoff frequency point
- 1kHz in this circuit
- Calculating cutoff frequency:
- FrequencyLow cutoff =

1
2∗pi∗R1∗C1

=

1
2∗pi∗1.5koℎm∗100nF

= 1 kHz

- Low pass filter:
- R2 and C2 form low pass filter
- LPF passes all frequencies below the frequency cutoff it was designed to
- Forms the upper cutoff frequency point
- 3.2 kHz in this circuit
- Calculating higher cutoff frequency
- FrequencyHigℎ cutoff =

1
2∗pi∗R2∗C2

=

1
2∗pi∗15koℎm∗3.3nF

= 3.2 kHz

- Gain of op amp
- gain(Av) = −

R2
R1

= −

15
1.5

= −10

- negative means that voltage output is inverted from voltage input
- it is important to follow max voltage guidelines
- for high frequency signals, it is best to use much higher speed op amp than LM741

Electronics Tutorials notes:

- understanding the op amp circuit
- Pin Out on Op Amp LM741
- Figured out that we need active band pass filter because passive band pass filter doesn’t amplify

February 7th Senior Design Task
Objective: Recreate an active bandpass filter

Approach for activity: Creating a circuit on breadboard

Outcome of activity: It didn’t work as we thought it did

Impact of activity on the project: Very big

Assessment of the importance of activity: Quite important

Tips to improve the approach for doing the activity for iterations: Make sure to learn the pinout of the op amp we actually have. Because we have dual op amp

Active inverting op amp bandpass filter:

Pin 3

Pin 2


- Circuit is using op amp LM358P which is a dual op amp and has a different pin out
- C1=10 nF
- C2=1 nF
- R1= 1 kohm
- R2= 7.5 kohm
- fc1 =

1
2∗π∗R1+C1

=16 kHz

- fc2 =

1
2∗π∗R2+C2

= 21 kHz

- LM358P pinout:

- Simulation was performed on Falstad Simulation Lab using the above circuit and values
- The results included output voltage of 15V for input voltage of 5V and every frequency that was set
- Dr. Yetkin agreed that simulation will be a waste of time with such high frequencies but said that simulation using NI Multisim is optional

Trial and error tips:

- If trying to see if phototransistor is working, flash an LED on it and see if the output on oscilloscope changes
- Connect phototransistor circuit onto Arduino and run AnalogReadSerialFast code; Look at the plot

February 8th Senior Design Task
Objective: To try create a 38 kHz active bandpass filter

Approach for activity: Simulated the circuit first which was Savannah’s work

Outcome of activity: It didn’t work out as we thought

Impact of activity on the project: Very big

Assessment of the importance of activity: Quite important

Tips to improve the approach for doing the activity for iterations: Make sure to learn the pinout of the op amp we actually have because we have dual op amp and we needed to use both sides

Testing simulated circuit:


Element w/ different value | New value
R1-S1 | 22 kohm
R3-S1 | 330 ohm
R2-S1 | 56 kohm
R1-S2 | 22 kohm
R3-S2 | 330 ohm
R2-S2 | 56 kohm
Table 4

February 18th Senior Design Task
Objective: Perform more testing using testing tools

Approach for activity: Connect to oscilloscope, multimeter, voltage source, Arduino etc to analyze the waveform generated

Outcome of activity: Had hard time analyzing the signal

Impact of activity on the project: Very big

Assessment of the importance of activity: Quite important

Tips to improve the approach for doing the activity for iterations: Make sure to have all the needed components like banana wires, oscilloscope wires etc

Test the following circuits together: 38 kHz waveform generator circuit and phototransistor circuit

- Channel 1 [yellow] : phototransistor circuit
- Fluctuating frequency
- Channel 2 [blue] : 38 kHz waveform generator circuit
- Results included the following measurements and waves:

February 21st Senior Design Task
Objective: Meet up with Dr. Yetkin and trouble shoot

Approach for activity: Scheduled a meeting with Dr. Yetkin and setup the circuits

Outcome of activity: Troubleshooted some part of it but still faced many challenges

Impact of activity on the project: Very big

Assessment of the importance of activity: Quite important

Tips to improve the approach for doing the activity for iterations: Make sure to setup the circuits and troubleshoot the whole setup beforehand

Tasks performed:

- Set up the same procedure with 38 kHz waveform generating circuit and phototransistor circuit
- Performed testing with Dr Yetkin
- Feedback:
- Waveform generator output was very noisy on oscilloscope this time
- We tried changing the probe, switching the parameters, applying trigger function but Dr. Yetkin believes it might be oscilloscope problem because the circuit was working before perfectly
- Need to find a better oscilloscope
- Phototransistor circuit problems include:
- Very low voltage output
- Has a lot of noise and we tried using two ways of looking at the output:

- Using Arduino, we were able to see some function waveforms
- Using oscilloscope, the output was very noisy and didn’t give much
- Feedback:
- We need to find a better oscilloscope
- We probably need to solder a new phototransistor with header wires
- Waveform generator function
- The waveform generator machine does not give out enough voltage
- Feedback:
- We need wires dedicated for the waveform generator machine
- Tips:
- On the oscilloscope probe, we switched the switch from 10K to 1K
- We need batteries, banana wires and other connecting wires, jumper wire kit
- Make sure to do sanity checks using multimeter and Arduino graphing

February 25th Senior Design Task
Objective: Soldering IR LED

Approach for activity: Soldered two jumper wires onto each side of the SMD IR LED

Outcome of activity: Was able to create an SMD IR LED that works

Impact of activity on the project: Very big

Assessment of the importance of activity: Quite important

Tips to improve the approach for doing the activity for iterations: Obtain all the components from the ERB lab before starting

Steps taken to solder IR LED:

- Use the tweezers in the NH 241 to put the SMD IR LED in between
- Turn on the soldering iron and smoke absorber
- Set the heating temperature at 350 C
- Heat one side of the SMD model for 2-3 sec
- Add some solder onto the heated part of the SMD model
- Have the jumper wire ready and heat up the jumper wire ending after placing it on one side of the SMD model
- Make sure the wire is not moving and that it is connected correctly
- If there is too much of wire sticking out, the SMD model may not work due to short circuitry
- Repeat the same steps for the other side of the SMD IR LED

February 26th Senior Design Task
Objective: Test the waveform generator with the phototransistor

Approach for activity: Setup the 38 kHz waveform generator with the phototransistor circuit

Outcome of activity: The phototransistor and waveform generator worked but amplifier didn’t

Impact of activity on the project: Very big

Assessment of the importance of activity: Quite important

Tips to improve the approach for doing the activity for iterations: Make sure to simulate the amplifier circuit before building it , because it didn’t work this time

Task 1: testing the 38 kHz waveform generator circuit

The following circuit was built and analyzed with following components:

- RA=5.1 kohm
- RB=33 kohm
- C1=10 nF
- C=1 nF
- Vin=3V
- RL=1 kohm
- SMD IR LED was connected to the output of the 555 timer and was used to transmit signals to the phototransistor

The following results were crucial to obtain:

- Vout=1.96 V
- Frequency: 37.3 kHz
- The frequency was oscillating within the range of ±2 kHz

Following was the circuit built:


The following measurements were obtained:

The following square waveform was obtained:

Task 2: using the above circuit with the phototransistor circuit and obtaining the results.

The phototransistor circuit is following:


The following components were used for the phototransistor circuit:

- R1=1Mohm
- Vin=3V

Following critical results were obtained:

- Vout= 150 mV
- This is very small for the input of 3V
- We used a very high resistor value but it still is very high
- Frequency=35.2 kHz
- This frequency kept oscillating as well

Important notes:
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

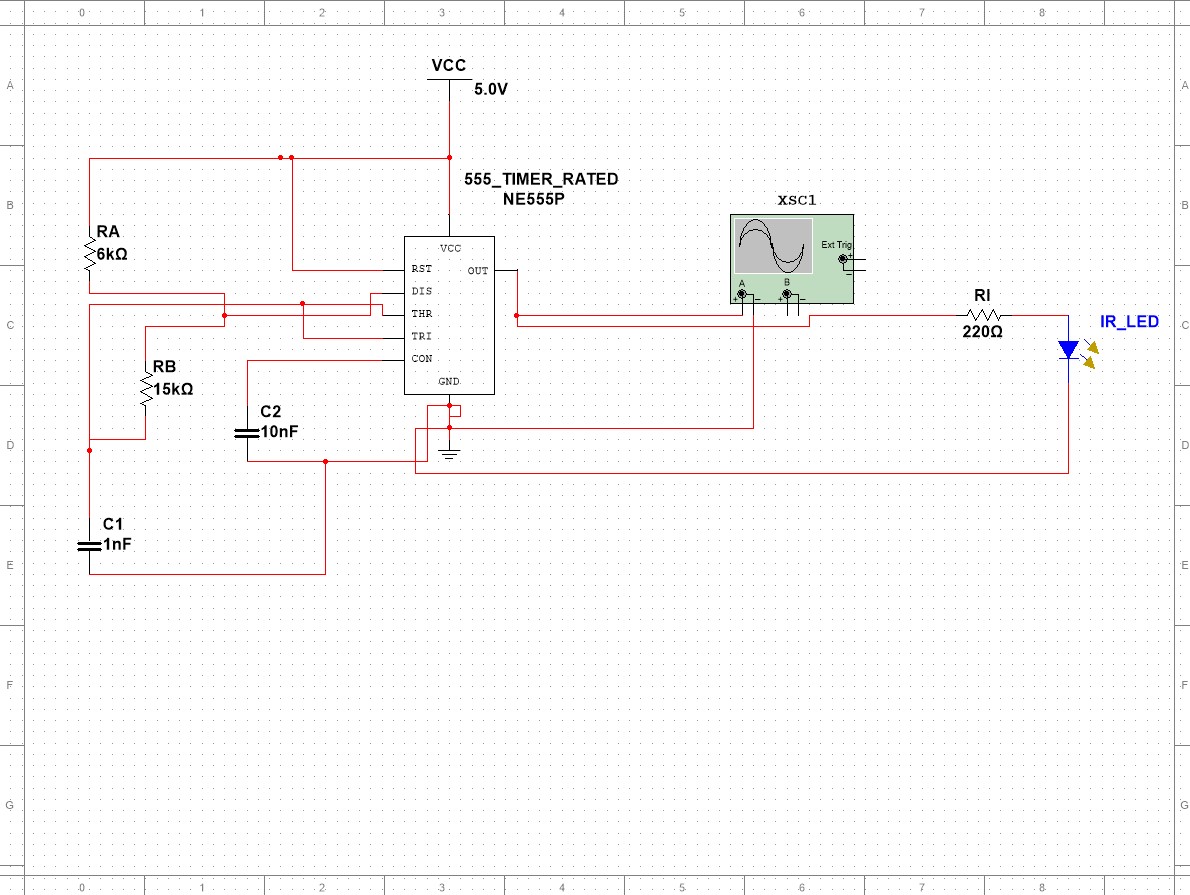
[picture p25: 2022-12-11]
MultisimDesigns/38kHz_WaveformGenerator_CircuitDiagram.jpeg

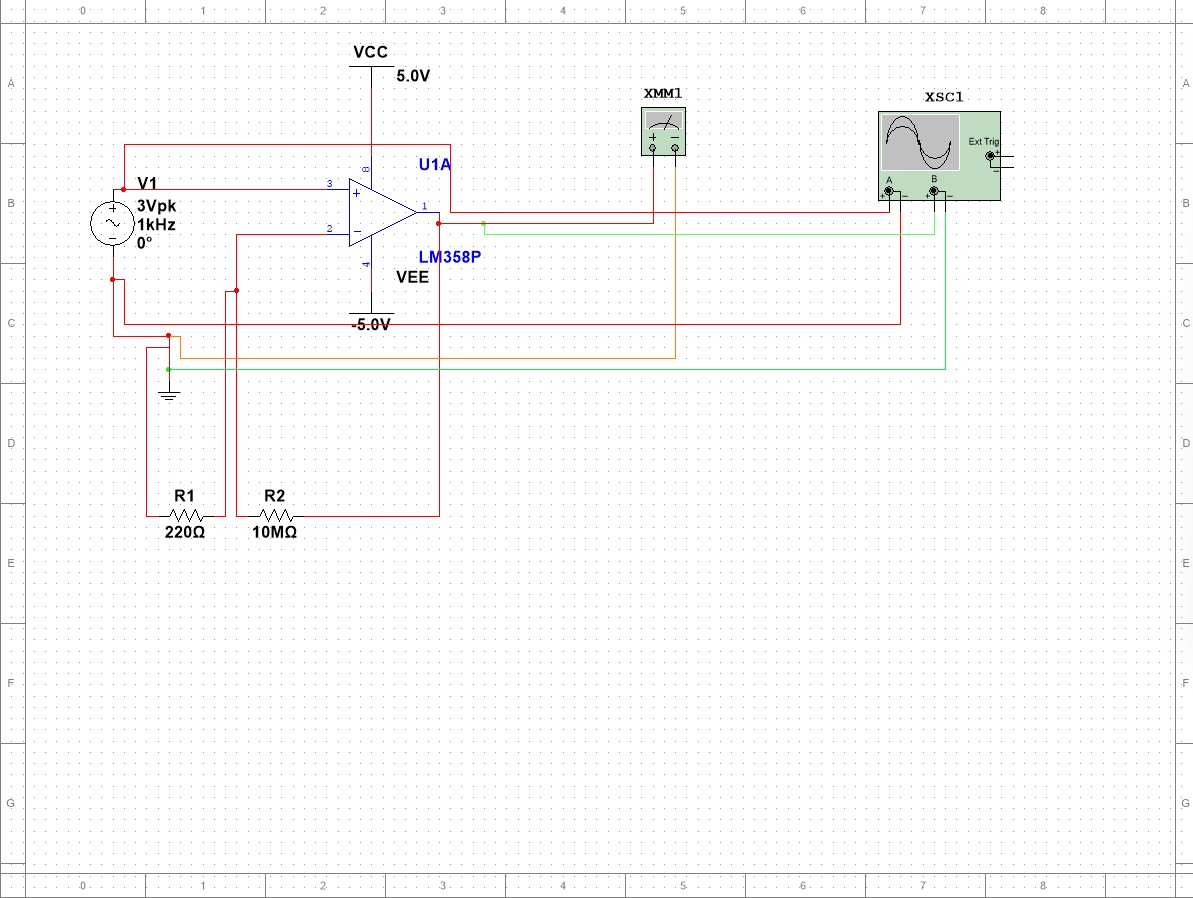
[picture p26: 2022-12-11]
MultisimDesigns/Amplifier_circuit_diagram.jpeg

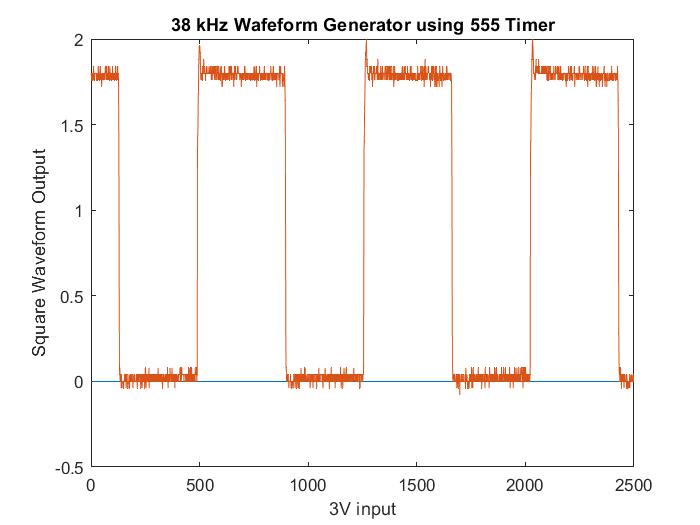
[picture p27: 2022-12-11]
MATLAB/Square_waveform_plot.jpg

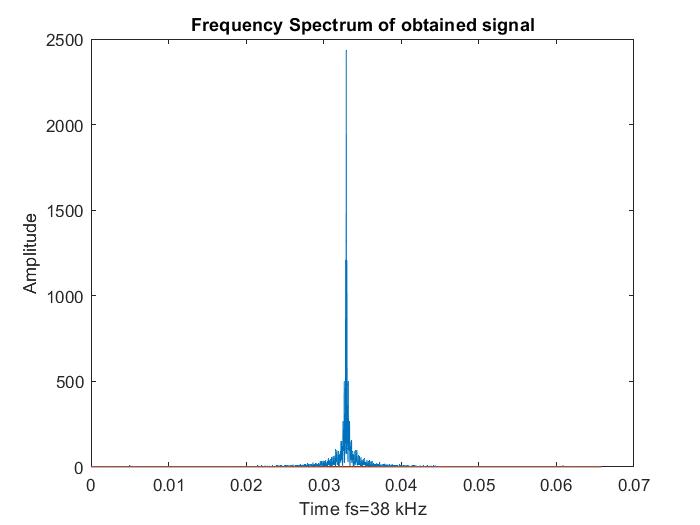
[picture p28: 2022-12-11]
MATLAB/FFT_plot.jpg

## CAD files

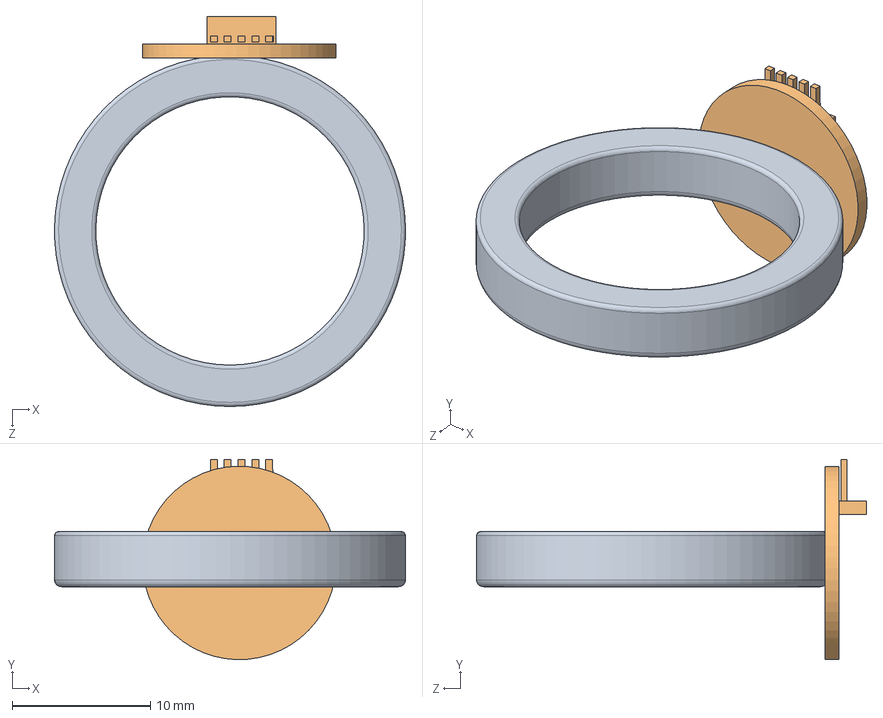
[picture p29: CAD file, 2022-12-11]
SolidWorksDesigns/Assembly of the thumb ring and tinylily.SLDASM
25.4 x 14.5 x 28.2 mm
Thumb
TinyLily

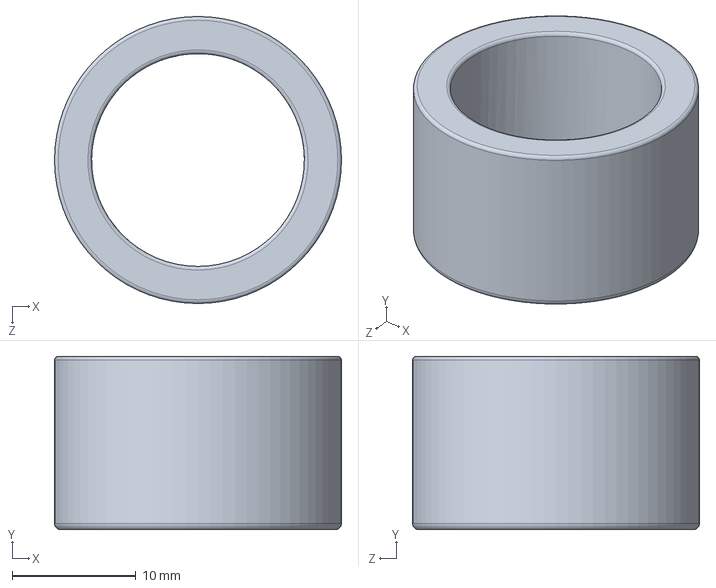
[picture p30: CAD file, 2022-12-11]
SolidWorksDesigns/Ring.SLDPRT
23.2 x 14.0 x 23.2 mm

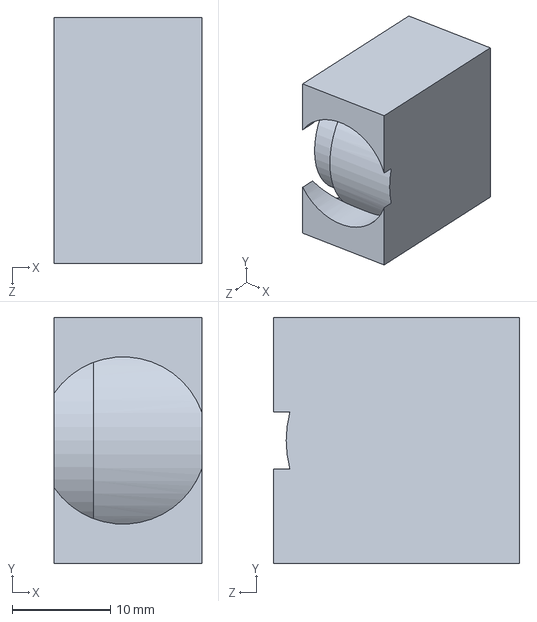
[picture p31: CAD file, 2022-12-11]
SolidWorksDesigns/TinyLilyRingMold2.sldprt
15.0 x 25.0 x 25.0 mm

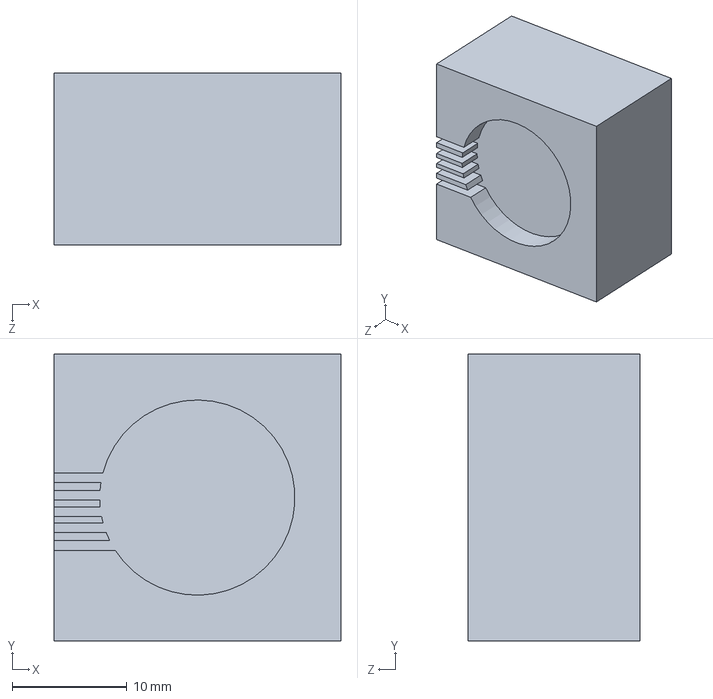
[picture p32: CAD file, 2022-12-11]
SolidWorksDesigns/TinylilyRingMold.sldprt
25.0 x 25.0 x 15.0 mm

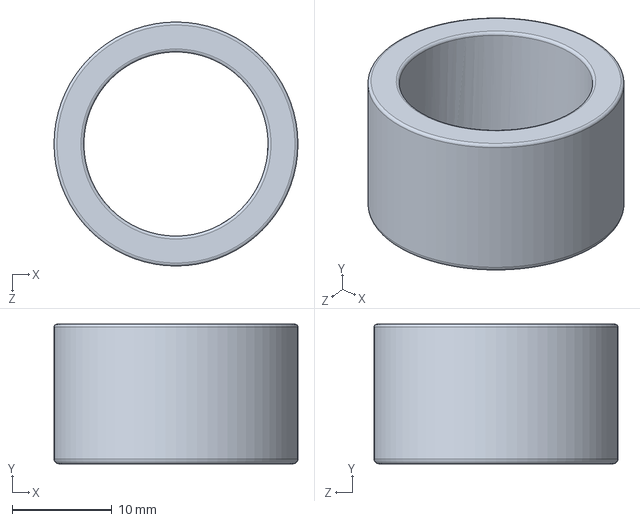
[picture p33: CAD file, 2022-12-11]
SolidWorksDesigns/Index.SLDPRT
24.5 x 14.0 x 24.5 mm

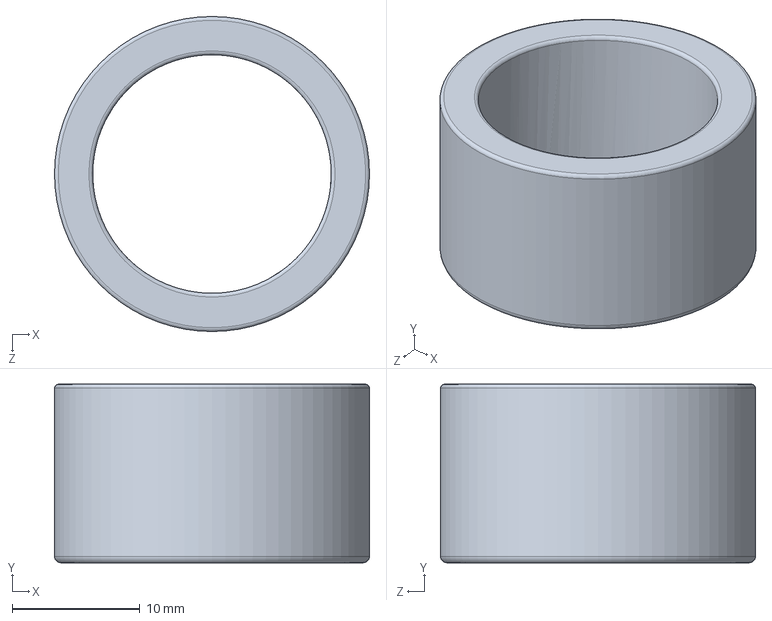
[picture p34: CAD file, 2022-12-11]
SolidWorksDesigns/MIddle.SLDPRT
24.7 x 14.0 x 24.7 mm

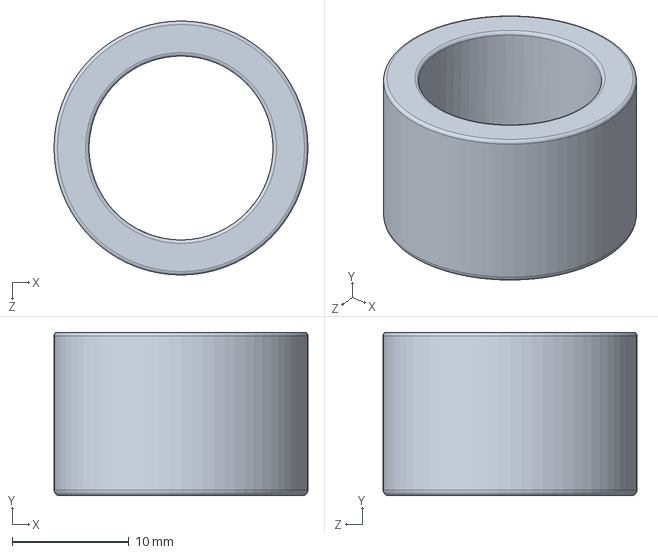
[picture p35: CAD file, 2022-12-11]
SolidWorksDesigns/Pinky.SLDPRT
21.8 x 14.0 x 21.8 mm

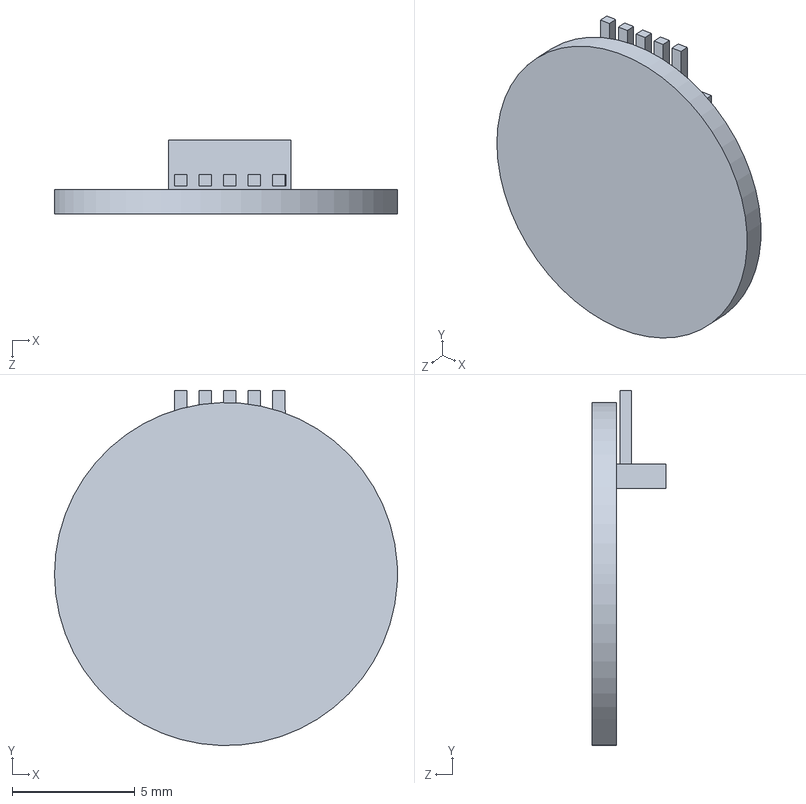
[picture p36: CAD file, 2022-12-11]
SolidWorksDesigns/TinyLily.SLDPRT
14.0 x 14.5 x 3.00 mm

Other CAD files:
SolidWorksDesigns/Assem1.SLDASM
SolidWorksDesigns/Thumb.SLDPRT
SolidWorksDesigns/DimensionDiagram_TinyLilyRing.slddrw

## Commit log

2022-12-11 SolidWorksDesigns
    Contains ring device designs, assembled TinyLily and ring device design, molds for assembly design
2022-12-11 MultisimDesigns
    Contains circuit designs and diagrams
